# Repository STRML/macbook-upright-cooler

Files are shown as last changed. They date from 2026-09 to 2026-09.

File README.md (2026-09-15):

# MacBook Upright Cooler

Experimental external cooling hardware for a 14-inch MacBook Pro M5 Max used in clamshell mode for sustained local-AI workloads and large code compiles.

The project started from the sealed-adapter approach demonstrated by Samuel Gregory with a llano V12 cooling pad, then branched into a smaller upright dock built around a standard 140 mm fan and a pressure plenum.

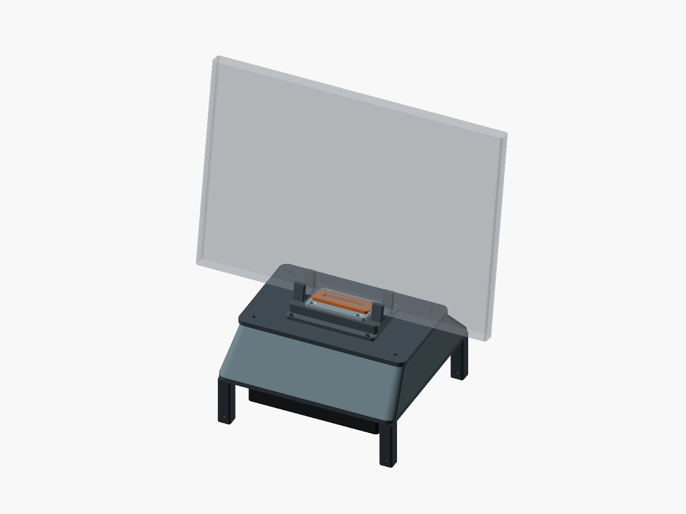
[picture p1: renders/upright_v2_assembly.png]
Upright V2 assembly


[V2 STLs](cad/upright_v2/stl/) · [Assembly guide](cad/upright_v2/README.md) ·
[Validation](docs/VALIDATION.md)

V2 is ready for construction and supervised fit checks. Cooling performance and
the final M5 Max interface have **not** been validated. Start with the blank insert.

For V12-powered validation, use the separate [V12 deck adapter](cad/upright_v2/v12_validation/README.md).
Its cooler footprint is unverified: print the small fit gauge and joint coupons
before committing to the full deck. It reuses V2's upper parts without a second fan.

## Current state

There are three prototypes in this folder:

1. **V12 adapter** - a split adapter for the llano V12, intended to test the sealed-pressure approach on the actual M5 Max.
2. **Upright V1** - a 140 mm fan below a plenum and a narrow gasketed outlet. Preserved as the original concept.
3. **Upright V2** - a tapered shell, removable fan cartridge, 10° cradle, padded stops, and replaceable center insert. The laptop interface remains provisional.

## Repository layout

- `cad/v12_adapter/` — current split V12 adapter STLs
- `cad/upright_v1/` — canonical parametric OpenSCAD source and matching STL
- `cad/upright_v2/` - V2 source, assembly guide, and verified STL snapshot; rebuilds go to `build/upright_v2/`
- `renders/` — current previews
- `docs/HANDOFF.md` — project state, decisions, unknowns, and next steps
- `docs/BENCHMARK_PLAN.md` — proposed A/B validation plan
- `docs/VENT_GEOMETRY.md` — supplied GLB/glTF measurements, online evidence, and remaining fit checks
- `tools/` — mesh validation and reference-model inspection
- `AGENTS.md` — instructions for Codex/other coding agents
- `archive/early_cadquery/` — an earlier CadQuery exploration; **not geometrically identical to the canonical V1 OpenSCAD model**

## Canonical upright V1 geometry

The authoritative source for Upright V1 is:

`cad/upright_v1/upright_macbook_140mm_pressure_dock_v1.scad`

Key dimensions:

- Overall printed envelope: approximately **176 x 176 x 129.5 mm**
- Standard 140 mm fan hole spacing: **124.5 mm**
- Fan opening: **136 mm**
- Laptop guide channel: **19 mm**
- Pressure outlet: **142 x 10 mm**
- Recessed gasket land around the outlet
- Four integrated feet leave space beneath a nominal 25 mm-thick fan

The checked-in STL is reproducible from the OpenSCAD file and is watertight.

## Build

Install OpenSCAD, then:

```bash
make stl
```

The rebuilt STL is written to `build/upright_macbook_140mm_pressure_dock_v1.stl`.

For a quick PNG render:

```bash
make preview
```

For V2's individual parts and assembled/exploded previews:

```bash
make stl-v2
make preview-v2
```

Install the optional Python validation dependencies and run `make check-v2` as
described in the [V2 guide](cad/upright_v2/README.md).

## Design priorities

The project is optimizing for **sustained performance**, not minimum chassis temperature.

- Keep the machine closed and upright if possible.
- Prefer external cooling; do not assume an internal thermal-pad mod is required.
- Feed the Mac's native cooling system with a sealed/pressurized supply rather than merely blowing room air at the bottom shell.
- Keep hot exhaust paths out of the pressurized intake region.
- Make the fan module replaceable so quiet axial fans and higher-static-pressure options can be tested without redesigning the dock.
- Instrument the laptop and compare work completed / clocks / package power over sustained runs.

## References

- [Samuel Gregory's pressure-cooling experiment](https://www.samuelgregory.co.uk/videos/i-sped-up-my-local-ai-64-with-this-100-gadget)
- [llano V12 reference cooler](https://www.amazon.com/dp/B0CYC7T38X)

## Status

This is prototype hardware. The supplied base-M5 visualization helped identify
separate hinge vent banks, but it does not establish a final M5 Max fit. V1's
142 mm outlet would overlap the outer banks in that asset; V2 uses a smaller
experimental center insert. Gasket placement, the closed-lid recess, and required
static pressure still need physical validation. See [vent geometry](docs/VENT_GEOMETRY.md).

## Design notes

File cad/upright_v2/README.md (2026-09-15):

# Upright V2

V2 is a printable construction and fit-check prototype with a removable 140 mm
fan cartridge, a shallow tapered plenum, and a replaceable laptop interface.
The closed laptop leans rearward by 10°. V1 remains unchanged.

**Start with the blank insert and an unpowered fan.** The supplied 3D reference
is a base-M5 visualization, not a verified M5 Max mechanical model. The 44 × 8 mm
open insert is an experimental bench part. Confirm the hinge recess, gasket
contact, and intake/exhaust boundaries before testing it on the Mac. See the
[measurements and sources](../../docs/VENT_GEOMETRY.md).

To supply air from the llano V12 instead of a standalone fan, see the separate
[V12 validation adapter](v12_validation/README.md). Start with its footprint gauge;
the existing V12 outline has not been fit-checked on the cooler.

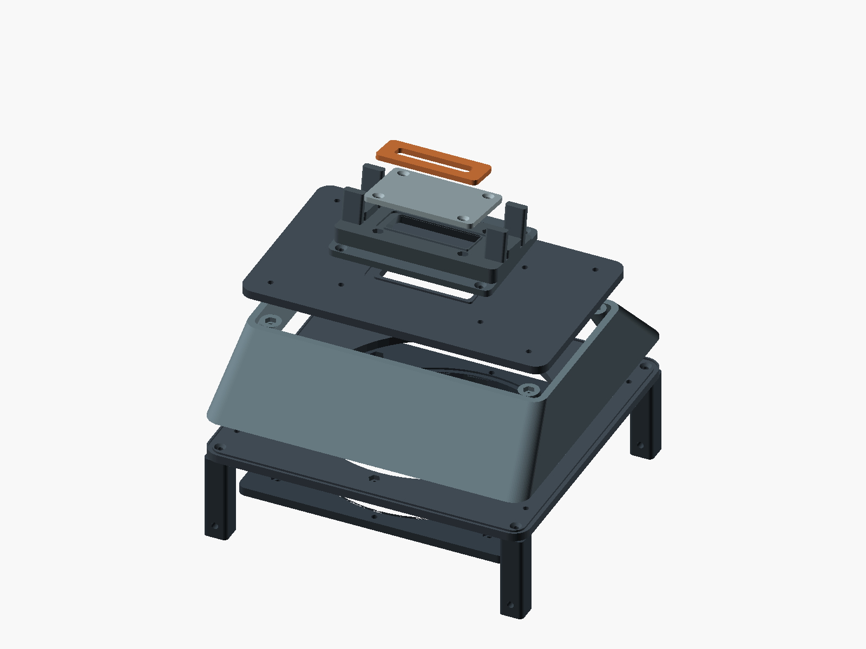
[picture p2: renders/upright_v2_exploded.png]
V2 exploded assembly


## Build and outputs

From the project root, with OpenSCAD installed, run:

```bash
make stl-v2
make preview-v2
python3 -m venv .venv
.venv/bin/pip install -r tools/requirements.txt
make check-v2 PYTHON=.venv/bin/python
```

Set `OPENSCAD` if the executable is not on your path. Outputs stay under
`build/upright_v2/`; `make stl` still builds V1. OpenSCAD's PNG renderer needs
access to a graphics context.

The [checked-in STL snapshot](stl/) contains the verified default prototype.
Rebuild after changing any parameter; the snapshot does not update automatically.
See the [validation record](../../docs/VALIDATION.md) for checks and limitations.

The source selector `PART` exports each part with its print base at Z = 0.
`PART="assembly"` displays the assembly, while `EXPLODE=20` separates it in
preview. `SHOW_REFERENCE` controls the illustrative fan and laptop envelope.
Those reference objects never enter STL exports. The assembly is for viewing;
print the individual parts.

## Parts and measured envelopes

All nine default exports passed the watertightness, consistent winding, positive
volume, and single-solid checks on September 15, 2026. Dimensions are in mm.

| STL | Quantity | Envelope | Print orientation |
|---|---:|---|---|
| `shell.stl` | 1 | 190 × 180 × 40 | Wide opening down |
| `base.stl` | 1 | 190 × 180 × 5 | As exported |
| `cartridge.stl` | 1 | 158 × 158 × 5 | Nut pockets up |
| `lid.stl` | 1 | 180 × 108 × 5 | As exported |
| `cradle.stl` | 1 | 96 × 64 × 29.24 | Flat flange down |
| `insert_blank.stl` | 1 initially | 64 × 42 × 3 | Countersinks up |
| `insert_open.stl` | Alternative | 64 × 42 × 3 | Countersinks up |
| `gasket.stl` | Foam template | 60 × 22 × 4 | Flat |
| `foot.stl` | 4 | 14 × 14 × 52 | Blind nut pocket up |

The assembled printed envelope is **190 × 180 × 129.24 mm**, excluding the laptop,
fasteners, and adhesive foot pads. The shell is 40 mm high, compared with V1's
55 mm plenum. The assembled height is nearly the same as V1 because the separate
cradle and insert need room above it.

Every part fits within a 190 × 180 mm rectangle. Allow room for a brim on the
printer. No split-body seam is needed on the project's nominal 250 mm bed.
Each foot includes a 2 mm square locating tongue that seats inside the base;
its exposed height is 50 mm. The tongue prevents rotation around the fixing bolt.

The shell has open top and bottom faces; its separate lid closes the chamber
after printing. The largest taper advances about 38 mm over 40 mm of height.
Nut-pocket roofs and the 4 mm cable-tie holes have short bridges. Inspect those
layers in your slicer before printing without supports. Mesh validation does not
replace a slicer check or load test.

## Hardware and sealing

Use a nominal 140 × 140 × 25 mm fan, with **124.5 mm** mounting-hole spacing.
It blows upward through a 136 mm opening. The nominal fan underside is 20 mm
above the desk. Fit a 140 mm intake guard before powering the fan, and keep
cables clear of its blades. The guard and fan power/control hardware are separate
parts; include the guard's thickness when choosing the M4 bolt length.

These are starting screw lengths for the modeled stack. Check your actual head,
washer, and fan dimensions before tightening; protruding screws must clear the
fan and neighboring parts.

| Joint | Screws | Nuts | Access |
|---|---|---|---|
| Feet to base | 4 × M3 × 12, countersunk | 4 × M3 | From above, before shell installation |
| Shell to base | 4 × M3 × 16, pan/socket head | 4 × M3 | From inside the open shell |
| Fan to cartridge | 4 × M4 × 30, pan/socket head | 4 × M4 | From below the fan |
| Cartridge to base | 4 × M3 × 12, pan/socket head | 4 × M3 | From below, outside the fan frame |
| Lid to shell | 4 × M3 × 12, pan/socket head | 4 × M3 | From above |
| Cradle to lid | 4 × M3 × 12, countersunk | 4 × M3 | From above the flange |
| Insert to cradle | 4 × M3 × 6, countersunk | 4 × M3 | From above, outside the contact strip |

Total: 24 M3 nuts and four M4 nuts. The nut-pocket allowances are parameters;
test a pocket before printing a full plate. Longer fans use a different `FAN_T`,
which increases the foot height and moves the complete body upward.

Apply closed-cell foam in the recessed seals at the base/shell, shell/lid,
lid/cradle, cradle/insert, and cartridge/base joints. The model seats rigid faces
together and gives the foam a 1.2 mm recess. Select foam that can compress into
that recess, then check for leakage. Seal pressure-chamber fasteners with suitable
bonded washers or a removable sealant; threads and printed nut pockets are not
airtight. Check the fan frame against the cartridge for leakage too.
The base/shell and shell/lid tracks are only 2 mm wide; carefully cut foam cord
or a suitable removable gasket compound may be easier than narrow foam strips.

For laptop contact, start with a **4 mm foam gasket**, using `gasket.stl` as a
cutting template. A TPU alternative needs a compression test before use. The
modeled compressed gasket is 3 mm high. It sits on the 3 mm insert, giving a
6 mm contact height measured perpendicular to the tilted seat. The rigid stops
are 5 mm high and need 1 mm soft pads to reach the same plane. Fit two 12 × 18 mm
stop pads and pad all four laptop-facing guide surfaces. Keep fastener heads
flush and away from the laptop.

## Assemble and test

1. Dry-fit the nuts and screws, then deburr the parts and fit the soft contact pads.
2. Fit the feet and captive base nuts. Seal and fasten the shell to the base.
3. Bolt the fan to its cartridge, then seal and screw the cartridge to the base.
4. Fit the lid's underside nuts before installing the cradle. Seal and fasten the lid.
5. Fit the insert nuts, insert seal, blank insert, and foam gasket.
6. Check the cradle with a padded dummy first. Verify that the stops carry the
   load and that the rigid insert cannot contact the laptop. The 5 mm lid spans
   an approximately 168 × 96 mm cavity and has not been load-tested. Apply the
   laptop-equivalent load at both stops, then a gentle lateral cable load. Stop
   if the lid bows, cracks, or lets the gasket/contact height change.
7. Check the actual Mac's hinge and vent geometry before an unpowered test fit.
8. With the laptop removed and fan guard fitted, bench-test leaks with the blank
   insert. Install the notched open insert only
   after confirming the inlet and exhaust separation, then follow the
   [benchmark plan](../../docs/BENCHMARK_PLAN.md).

The four cartridge screws are separate from the fan bolts and the feet. With the
laptop removed and power disconnected, release those four screws and lower the
fan/cartridge assembly. The shell, lid, and cradle stay together.

Use the holes near the bottoms of the feet for cable ties on either side. Route
the fan cable along a foot and keep the underside inlet clear. The short central
guides leave the laptop's side ports accessible.

## Parameters to verify on the machine

`INTAKE_CENTER_X_TBD`, `INTAKE_W_TBD`, `INTAKE_D_TBD`, and
`EXHAUST_START_ABS_X_TBD` are provisional. The raised cradle ends at X = ±48 mm;
the default exhaust keepout starts at ±52 mm. The stops occupy X = 36..48 mm and
−48..−36 mm. These positions use the gaps in the reference mesh, so they require
checking on the actual Max.

`CHANNEL_W`, `GUIDE_PAD_T`, the gasket dimensions, and its compressed thickness
control contact and fit. Changes outside the documented lean and fan-thickness
options need fresh assembly and clearance checks. The source is editable; its
assertions do not cover every possible combination.

Still to validate physically: printing tolerances, rigidity under cable pull,
gasket compression, vent alignment, exhaust recirculation, fan pressure, and
sustained workload throughput. A watertight STL describes a closed geometric
solid; it does not prove an FDM print or its assembled seams are airtight.

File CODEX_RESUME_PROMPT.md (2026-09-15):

# Codex Resume Prompt

Resume this physical-design project from the repository state.

Read `AGENTS.md`, `README.md`, `docs/HANDOFF.md`, and `docs/BENCHMARK_PLAN.md` first. The current user goal is an elegant upright pressure-cooling dock for a 14-inch M5 Max MacBook Pro in clamshell mode, primarily for sustained AI work and code compiles.

Do not redesign or overwrite `upright_v1`; use it as a baseline. Upright V2 now
exists in `cad/upright_v2/`. Read its `README.md` and `docs/VENT_GEOMETRY.md`
before changing it. It has a replaceable 140 mm fan cartridge, a tapered plenum,
10-degree cradle, replaceable gasket insert, padded stops, and cable-tie paths.

The user supplied `macbook_pro_14-inch_m5.zip` and `macbook-pro-14-inch-m5.zip`
in Downloads. Their GLB/glTF contains useful visualization geometry for a base
M5, but is not a verified M5 Max mechanical model. The central vent-bank frame
is about 51 mm wide, so V2 replaces the V1-sized 142 mm outlet with an explicitly
provisional 44 x 8 mm center opening plus a blank fit-check insert. Preserve the
source qualification and uncertainty documented in `docs/VENT_GEOMETRY.md`.

Next: confirm the actual Max's closed-lid vent recess and padded contact points,
then print/fit-check, leak-test, and benchmark. Generated V2 meshes and previews
are under `build/upright_v2/`; use `make stl-v2`, `make preview-v2`, and
`make check-v2` to reproduce them. The verified snapshot is in
`cad/upright_v2/stl/`; do not let it silently drift from the source. The public
repository is `STRML/macbook-upright-cooler`. Check Git/GitHub state before edits.

The separate `cad/upright_v2/v12_validation/` adapter connects V2's unchanged
upper assembly to a provisional llano V12 deck. The user explicitly has NOT
fit-checked the old V12 panels. Start with `make gauge-v12` and `make coupon-v12`,
then measure the real cooler and establish positive housing restraint before a
powered test. Read that adapter's README for the supported workflow. The source
does not model an unverified V12 body or attachment route. Follow the user's
direct-main publishing instruction; do not open another PR for this work.

The user chose V12 validation first, with standalone intake-clearance, lid-rib,
support, and larger-insert proposals recorded in `docs/BENCHMARK_PLAN.md` for
later. Do not implement those proposals as part of finishing the V12 adapter.
The intended fan direction is pressure into the center hinge intake, with outer
hinge exhausts and side intakes clear. Read the airflow section in
`docs/VENT_GEOMETRY.md` before changing that path.

Important: do not guess final MacBook vent dimensions. Parameterize uncertain geometry and clearly identify measurements that must be taken from the physical machine or a trustworthy mechanical reference before a final STL is produced.

When you generate CAD:

- keep editable source in the repo
- export STL for print testing
- generate a preview image
- report overall dimensions and mesh watertightness
- preserve V1 files unchanged
- explain any assumptions that affect airflow or laptop fit

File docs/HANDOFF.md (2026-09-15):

# Project Handoff

## Resume state: September 15, 2026

Upright V2 now has editable CAD, individual prototype STL exports, and assembly
previews. Start with [the V2 guide](../cad/upright_v2/README.md) and
[the reference-model findings](VENT_GEOMETRY.md). V1 is unchanged.

The supplied Downloads GLB/glTF represents a base M5 and contains useful hinge
detail, but is not a certified M5 Max mechanical reference. Its center-bank
frame is about 51 mm wide; V1's 142 mm outlet would cross into the neighboring
banks in that asset. V2 therefore has a blank insert plus a provisional 44 × 8 mm
center-window insert, with raised hardware confined to a 96 mm-wide cradle.

Next physical step: validate the hinge recess, vent boundaries, and padded stop
locations on the actual Max, using the blank insert first. Then leak-test the
assembled parts and run the benchmark plan. The public repository is
[`STRML/macbook-upright-cooler`](https://github.com/STRML/macbook-upright-cooler).
The user requested direct publication to `main`, without a PR. Check Git and
GitHub before edits. Physical validation is tracked in
[issue #2](https://github.com/STRML/macbook-upright-cooler/issues/2), followed by
[performance testing in #3](https://github.com/STRML/macbook-upright-cooler/issues/3).

## V12 validation adapter

The user asked to adapt V2's bottom for the llano V12 and confirmed that the old
split V12 panels have **not** been fit-checked. The separate
[adapter guide](../cad/upright_v2/v12_validation/README.md) covers a four-piece
footprint gauge, three joint coupons, and a bolted four-tile deck with a continuous
collar. V2's original source and parts remain unchanged; V12 mode removes its fan,
cartridge, and feet.

Next: print the gauge and coupon parts, check the actual cooler's foam/contact
geometry, and identify a safe housing restraint. Do not treat the inherited
381 × 269 mm outline or its 30 mm corner radius as verified V12 dimensions.
Powered use also requires the adapter's load, seal, and stability checks, plus
the existing Mac-side fit checks. No V12 body, foam, or strap route is invented
in the CAD.

The user chose to finish this adapter before revising standalone V2. External
review proposals for 30-35 mm fan clearance, lid ribs, narrower supports, and
measured insert variants are recorded in the benchmark plan. Air is pushed into
the center hinge intake; the outer hinge exhausts and side intakes remain open.
The user's hand check supports that direction, but actual vent boundaries and
flow under external pressure still need checking.

## Goal

Create an elegant, compact external cooling dock for a **14-inch MacBook Pro M5 Max** used primarily in **clamshell mode** for:

- sustained local AI / ML inference and prompt processing
- repeated or large code compiles

The design should recover as much sustained SoC performance as practical without opening the MacBook or adding internal thermal pads unless external airflow proves insufficient.

## Why this exists

The 14-inch Max chassis has substantially less sustained thermal capacity than the 16-inch chassis under heavy combined workloads. The working hypothesis is that a sealed high-static-pressure air supply can improve the Mac's native intake airflow enough to materially delay or reduce throttling.

The Samuel Gregory experiment is the main inspiration: a gaming-laptop pressure cooler plus a custom adapter/seal produced a large sustained local-AI improvement on a 14-inch M5 Max. This repo first reproduces that basic pressure-cooling concept, then aims to package it as a vertical dock.

## Current prototypes

### A. V12 split adapter

Files:

- `cad/v12_adapter/panel_left.stl`
- `cad/v12_adapter/panel_right.stl`

These are a small reconfiguration of the adapter concept used in the Gregory video, sized/split for printing. Each half is approximately 208.5 x 269 x 2 mm and watertight. The assembled panel is roughly 381 x 269 mm. The current interlocking-joint target gap is about 0.2 mm.

Purpose: validate the performance effect on the actual Mac before spending time optimizing aesthetics.

### B. Upright 140 mm pressure dock V1

Files:

- `cad/upright_v1/upright_macbook_140mm_pressure_dock_v1.scad`
- `cad/upright_v1/upright_macbook_140mm_pressure_dock_v1.stl`

Concept:

- standard 140 mm fan mounted underneath
- large low-velocity pressure chamber
- narrow gasketed outlet at the top
- 19 mm channel to guide a closed MacBook vertically
- short rails so the dock does not wrap unnecessarily far around the chassis
- exhaust should remain outside the pressurized volume

Canonical V1 dimensions are parameterized at the top of the OpenSCAD file.

## Important design decisions already made

1. **Do not start with thermal pads.** External pressure cooling gets first priority because it is reversible and there is encouraging evidence it can materially improve sustained AI performance.
2. **Static pressure matters.** A 140 mm form factor is convenient, but the project should not assume a quiet case fan is sufficient. The design should make fan substitution easy.
3. **Avoid a narrow remote hose unless packaging requires it.** Direct fan -> plenum -> gasket is preferred because it minimizes pressure losses.
4. **Preserve intake/exhaust separation.** Hot hinge exhaust must not be encouraged back into the pressure inlet.
5. **Benchmark performance, not just temperature.** A cooler chip at the same sustained package power is less valuable than a hot chip sustaining more useful work.
6. **Keep the current V1 as a baseline.** Make substantial changes as V2 rather than silently mutating V1.

## Unknowns that must be resolved

- Exact location and dimensions of the 14-inch M5 Max intake and exhaust openings in clamshell orientation.
- How much of the rear/hinge intake can practically be sealed to the plenum without restricting exhaust.
- Whether the side intakes need their own pressurized branches or whether feeding the central/rear intake is sufficient.
- Required fan pressure/flow. This should be learned from V12 RPM sweeps before selecting the final standalone fan.
- Best laptop lean angle. A slight rearward lean may provide passive sealing force and improve stability.
- Gasket material/thickness and how much compression is appropriate without scratching or loading the enclosure.
- Whether the V1 19 mm channel is ideal once actual gasket material is selected.

### C. Upright V2 construction and fit-check prototype

- Source: `cad/upright_v2/upright_macbook_140mm_pressure_dock_v2.scad`
- Build: `make stl-v2`, `make preview-v2`, and `make check-v2`
- Individual outputs: `build/upright_v2/`
- Published prototype snapshot: `cad/upright_v2/stl/`
- Printed assembly envelope: 190 × 180 × 129.24 mm at 10° lean
- All nine default STL variants are watertight single solids. The cradle also
  passes at 8° and 12°. These checks do not establish physical print strength,
  airtightness, or final laptop fit.

The shell prints open at both ends and receives a separate lid. Its cartridge
retainers are independent of the fan bolts and feet. Replaceable foam seals join
the pressure parts; the laptop gasket and padded stops share a tilted contact
plane. Cable ties attach through the feet, outside the pressure chamber.

## Original V2 design brief

V1 was inspected before V2 was built. The design brief called for:

- removable 140 mm fan cartridge using standard 124.5 mm mounting pattern
- optional adapters for thicker/high-pressure 140 mm fans
- lower, more sculpted wedge/plenum rather than a rectangular tower
- 8-12 degree rearward laptop lean as a parameter
- replaceable TPU/foam gasket insert rather than relying on hard printed surfaces for the seal
- positive mechanical stop so the Mac cannot drop into the air outlet
- cable routing that works with both left and right USB-C/Thunderbolt connections
- no obstruction of the hinge exhaust zones
- easy disassembly for fan testing
- geometry that can be printed on a typical ~250 mm bed, splitting the body if necessary

The default V2 parts fit inside 190 × 180 mm, so a split-body variant was not
needed. Fan selection and final laptop fit remain experimental.

## Canonical vs archived CAD

The OpenSCAD V1 is canonical. `archive/early_cadquery/` contains an earlier CadQuery/STEP exploration with different base/plenum dimensions. It is retained only as design history and should not be treated as the source for V1.

## Source references

- Gregory experiment: https://www.samuelgregory.co.uk/videos/i-sped-up-my-local-ai-64-with-this-100-gadget
- Reference llano V12: https://www.amazon.com/dp/B0CYC7T38X

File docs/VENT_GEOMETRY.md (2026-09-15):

# Laptop reference geometry

The supplied 3D model supports a narrower center interface for V2. It does **not**
establish a production fit for the M5 Max. Measurements below describe surfaces in
a visualization mesh, including frames and covers, rather than certified vent
apertures. Inspected on September 15, 2026.

## What is confirmed

Apple specifies a **312.6 × 221.2 × 15.5 mm** outer envelope for the 2026 14-inch
M5 Pro/Max. Its service illustrations show two fans, their ducts, and a separate
rear vent/antenna module. Neither the specification nor the inspected service
pages provides dimensions for individual openings.

Sources: [Apple specifications](https://support.apple.com/en-gb/126318),
[Apple exploded view](https://support.apple.com/en-us/125815), and
[Apple vent module procedure](https://support.apple.com/en-us/125803).

SVALT, a cooling-hardware manufacturer, describes the 14-inch Pro/Max family as
having side intakes and a central hinge intake, with hot exhaust at both hinge
ends. Its separate base-M5 description identifies a single fan. This supports
the airflow concept but does not prove that the two models have identical vent
dimensions. [SVALT model guide](https://svalt.com/blogs/svalt/laptops).

## Airflow direction

The intended stock flow for the two-fan Pro/Max is:

| Opening | Stock direction | Dock treatment |
|---|---|---|
| Center hinge vent | Cool air enters | Feed from the sealed center insert |
| Left and right outer hinge vents | Hot air leaves | Keep outside the seal and clear of supports |
| Side chassis slots | Cool air enters | Leave open; do not tape them shut |

This follows SVALT's description for the 2021-2026+ 14-inch M1-M5 Pro/Max
family, not its separate single-fan base-M5 entry. Apple service drawings support
the two-fan layout but do not establish flow direction at every opening. On
September 15, 2026, the user reported hot outward flow at the outer hinge vents,
apparent intake at the center, and cool side slots. That is consistent with the
description, but is not a measured flow map.

V2 pushes air into the center intake. With a standalone fan, its intake faces the
desk and its discharge faces the plenum; check the fan's airflow arrow or actual
flow before installation. With the V12 adapter, the V12 supplies the pressure and
the standalone fan is removed. Pulling through the same center connection would
oppose its normal intake role. Exhaust extraction would need a different adapter
at the two outer vents and is not part of this design.

Before fitting the dock, check direction during a sustained load with a narrow
paper strip held securely a few millimeters outside each opening. Never insert
it, release it, or cover the vent. Record movement toward or away from the case;
temperature alone cannot establish direction. Repeat with the pressure source
at low speed after all mechanical checks pass. Added pressure may send some air
out through the side intakes instead of through the heatsinks. Keep them open
and record that behavior during the speed sweep rather than assuming all added
flow follows the intended path.

## Supplied files and provenance

The two Downloads archives contain an open-lid model:

- `macbook_pro_14-inch_m5.zip`: `scene.gltf`, `scene.bin`, textures, and a license.
- `macbook-pro-14-inch-m5.zip`: `source/macbook_pro_14_inch_M5.glb` and textures.

The glTF metadata credits “Apple User” and links to
[MacBook Pro 14-inch M5 on Sketchfab](https://sketchfab.com/3d-models/macbook-pro-14-inch-m5-652a992f4f244122ae251f9cbb81da1e).
The archive entries date to October 15, 2025. This predates the 2026 M5 Pro/Max.
The metadata does not establish that this is an Apple engineering model.

Both formats contain 44 geometries and 163,918 triangles, with matching scene
bounds. At the glTF meter-to-millimeter scale, width is **311.730 mm**. Scaling
that width to Apple's envelope requires a factor of **1.00279135**. The values
below retain the original scale; scaling the whole mesh would not resolve its
model identity or modeling tolerances.

The originals remain in Downloads. They are not redistributed with the dock.
Archive SHA-256 values identify the inspected inputs:

```text
macbook_pro_14-inch_m5.zip
8e0a6a0f3d5dbc4d95af7a3dc4d497db02db5f969b665d1a111a3dfa906ae67f
macbook-pro-14-inch-m5.zip
23eaa3a1fac218d26dcd32061c8e82add21565c6362a2ae14dc4012e4c40db4a
```

## Geometry recovered from the mesh

Coordinates use X across the laptop, Y upward through its thickness, and Z from
the hinge toward the front. X = 0 is approximately the centerline. Apply each
scene-node transform before measuring vertices.

The connected surfaces of glTF node `Object_44` provide these bounds, in mm:

| Surface | X minimum | X maximum | Width |
|---|---:|---:|---:|
| Rear center-bank frame | −25.285 | 25.286 | 50.571 |
| Rear left-bank frame | −118.884 | −54.466 | 64.418 |
| Rear right-bank frame | 54.467 | 118.884 | 64.417 |
| Inner center-bank surface | −26.559 | 26.560 | 53.119 |

The rear frames extend from Y = −6.737 to 2.353 mm and Z = −104.820 to
−102.342 mm. Their height includes structure hidden by the hinge. **Do not use
9.09 mm as the clear clamshell opening height.** The hinge recess and closed-lid
occlusion still need measurement on the machine.

Node `Object_40` also has long side surfaces spanning Z = −20.200 to 86.475 mm.
These are visual backing surfaces, so their bounds do not establish side-intake
aperture dimensions.

To reproduce the measurements and orthographic reference image after extracting
the glTF archive, run:

```bash
python3 -m venv .venv
.venv/bin/pip install -r tools/requirements.txt
.venv/bin/python tools/inspect_reference.py /path/to/extracted/scene.gltf
```

The image is written to `build/upright_v2/reference.png`.

## V2 decisions and remaining fit checks

V1's 142 mm-wide outlet reaches X = ±71 mm. It would overlap both outer banks in
this asset. V1 remains preserved as a historical baseline; V2 uses an explicitly
experimental 44 × 8 mm center window and a blank insert for initial fit and leak
checks. This is a design choice inside the estimated center bank, not a measured
Mac aperture. A small port may also limit airflow; benchmark it before selecting
the final size or fan.

V2 keeps its raised central cradle inside a provisional X = ±52 mm exhaust
keepout and locates padded supports in the gaps beside the center bank. The seal
and supports are replaceable so that physical measurements can correct them.

Before cooling the laptop through the insert:

1. Confirm the center intake and both exhaust boundaries on the actual M5 Max.
2. Measure the closed-lid opening height and recess from the lowest hinge edge.
3. Check that padded stops land on solid chassis and keep rigid parts clear.
4. Verify gasket contact and airflow direction, then follow the
   [benchmark plan](BENCHMARK_PLAN.md).

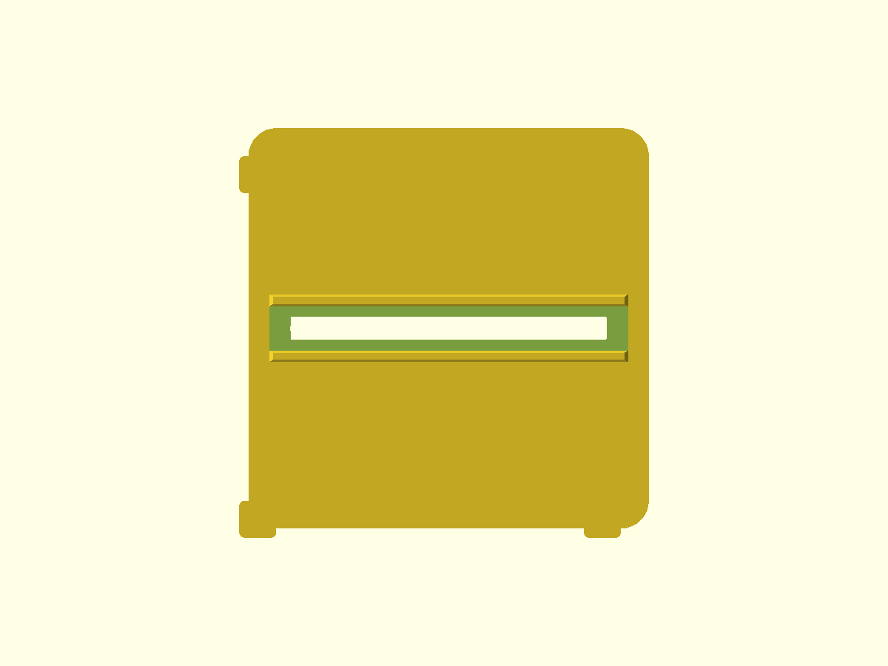
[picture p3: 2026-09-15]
renders/upright_macbook_140mm_pressure_dock_v1_preview.png

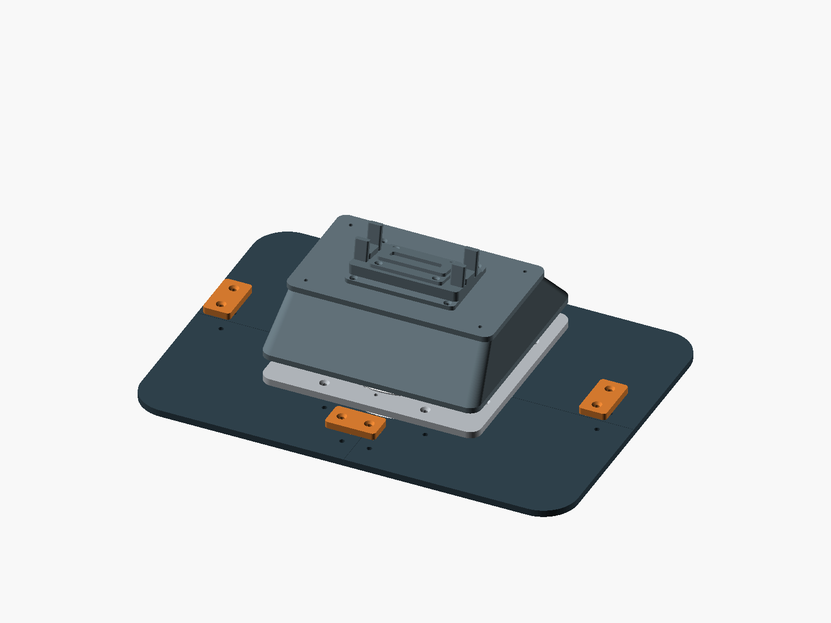
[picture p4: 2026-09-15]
renders/upright_v12_exploded.png

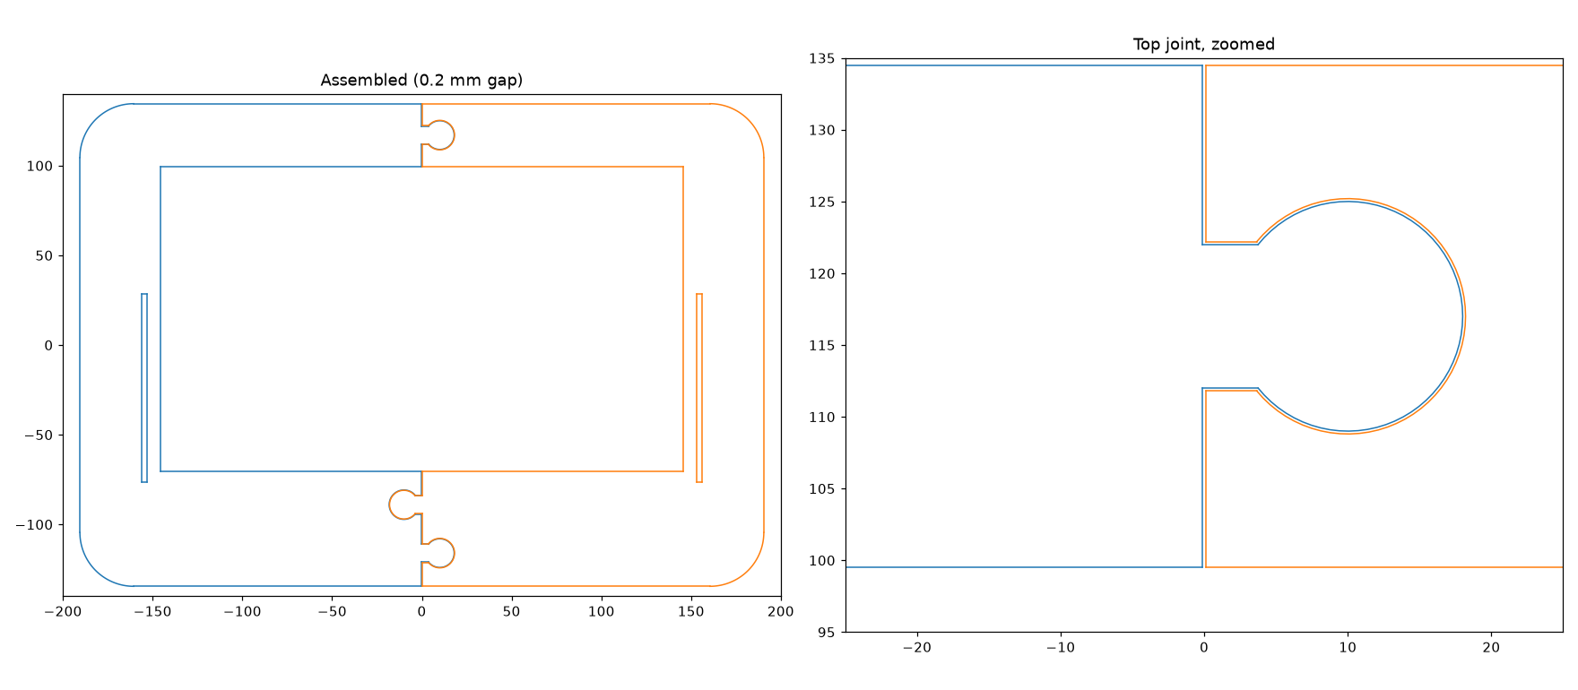
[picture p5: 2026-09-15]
renders/v12_adapter_split_preview.png

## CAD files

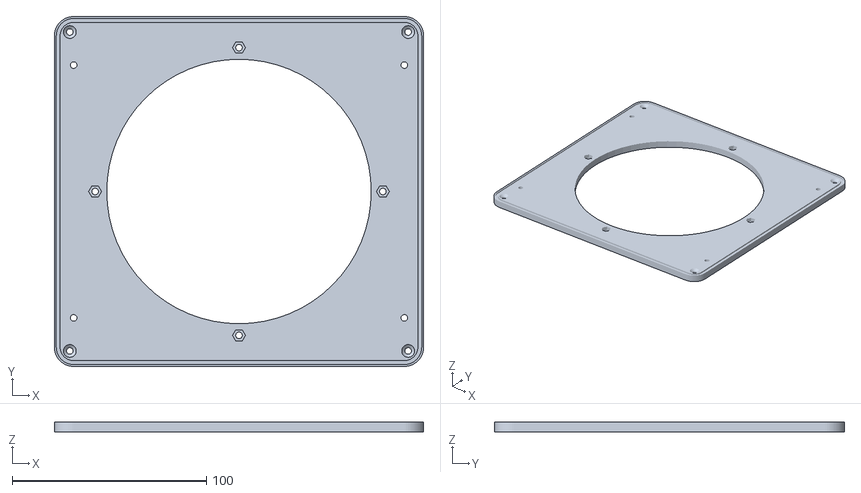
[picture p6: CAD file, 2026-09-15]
cad/upright_v2/stl/base.stl
190.0 x 180.0 x 5.00

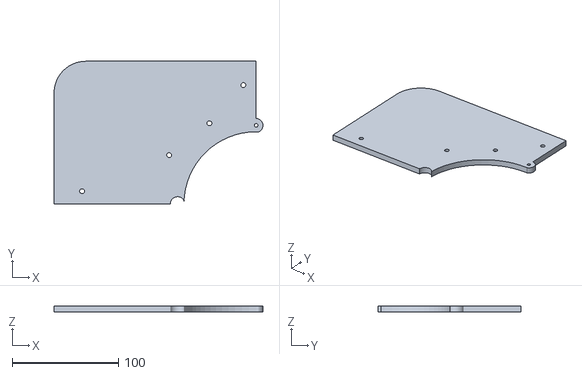
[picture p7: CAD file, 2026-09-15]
cad/upright_v2/v12_validation/stl/deck_nw.stl
197.0 x 134.3 x 6.00

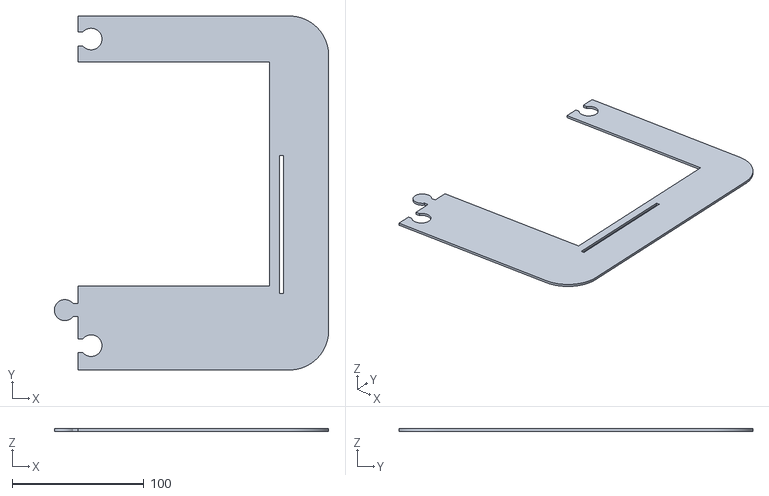
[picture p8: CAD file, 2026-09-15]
cad/v12_adapter/panel_right.stl
208.5 x 269.0 x 2.00

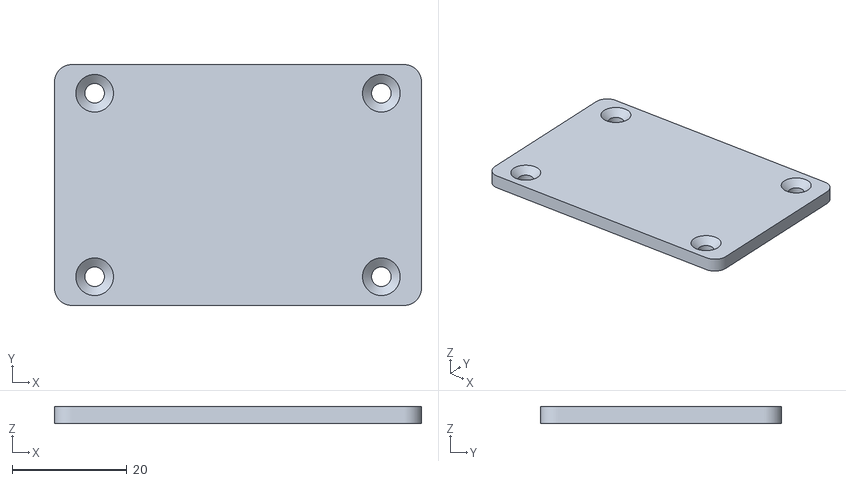
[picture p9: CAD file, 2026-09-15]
cad/upright_v2/stl/insert_blank.stl
64.0 x 42.0 x 3.00

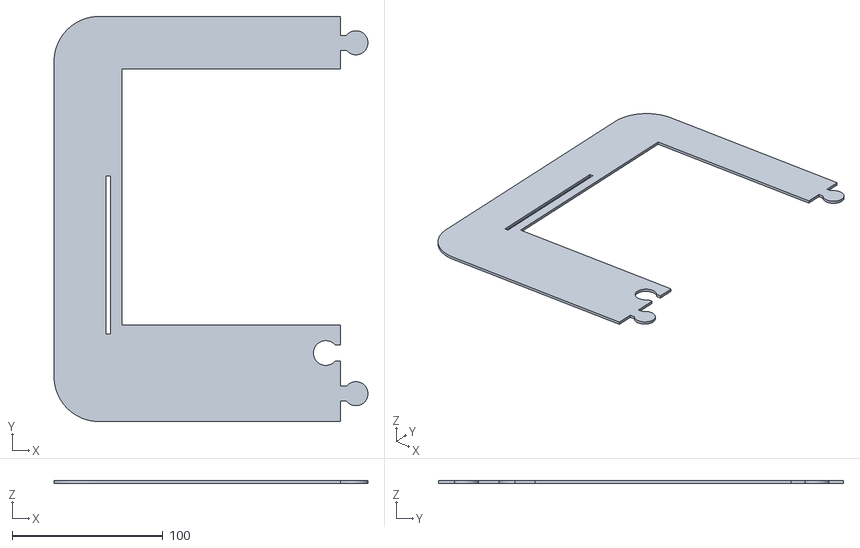
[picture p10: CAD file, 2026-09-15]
cad/v12_adapter/panel_left.stl
208.5 x 269.0 x 2.00

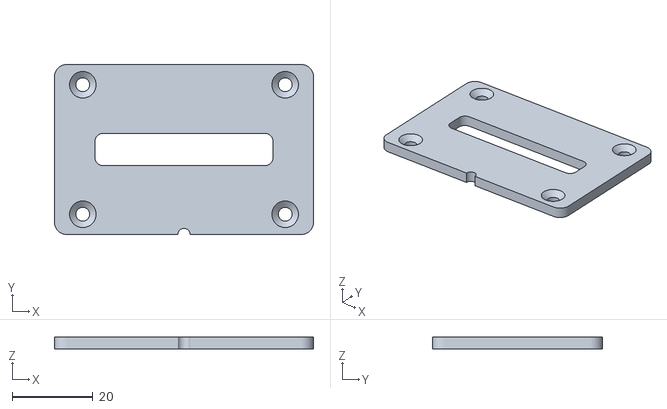
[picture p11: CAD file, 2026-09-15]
cad/upright_v2/stl/insert_open.stl
64.0 x 42.0 x 3.00

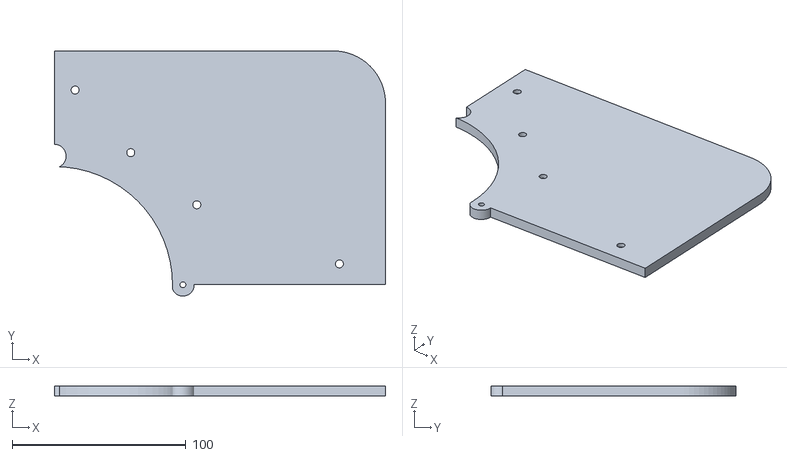
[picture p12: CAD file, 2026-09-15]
cad/upright_v2/v12_validation/stl/deck_ne.stl
190.3 x 141.0 x 6.00

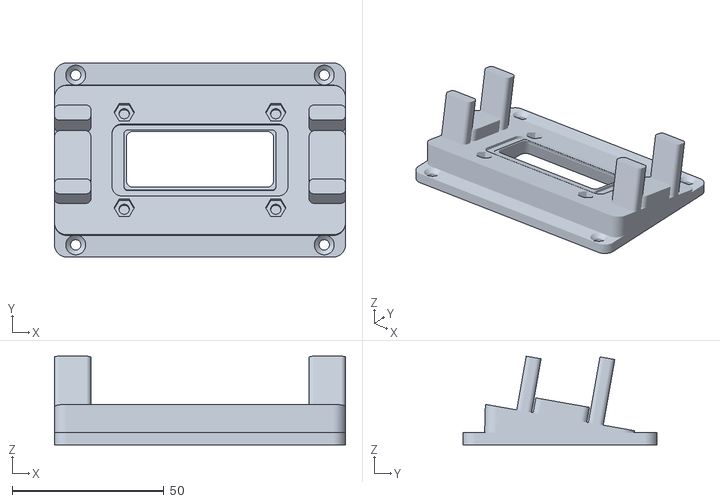
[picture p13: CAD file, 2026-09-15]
cad/upright_v2/stl/cradle.stl
96.0 x 64.0 x 29.2

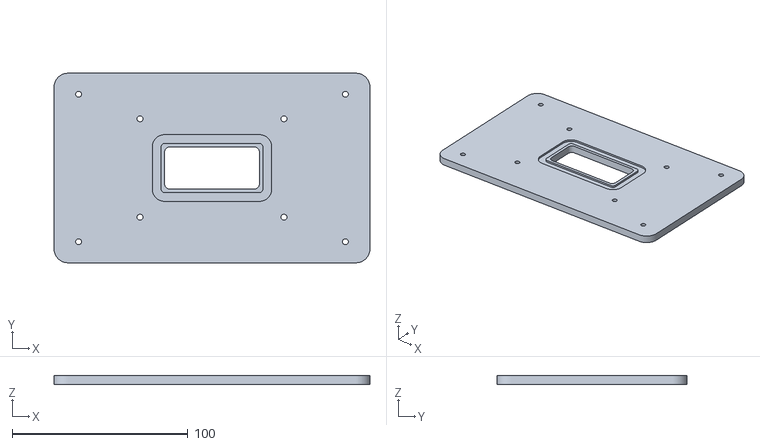
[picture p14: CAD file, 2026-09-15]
cad/upright_v2/stl/lid.stl
180.0 x 108.0 x 5.00

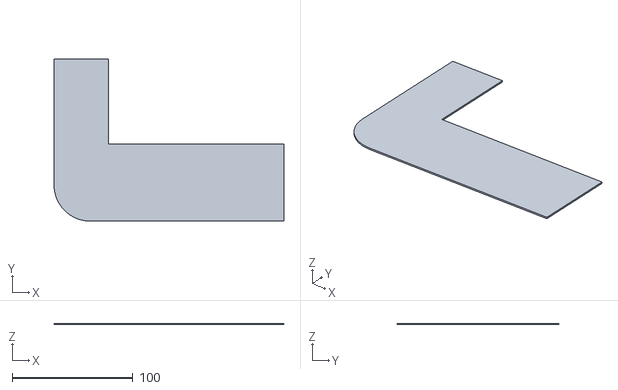
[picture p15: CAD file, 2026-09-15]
cad/upright_v2/v12_validation/stl/gauge_sw.stl
190.4 x 134.4 x 1.20

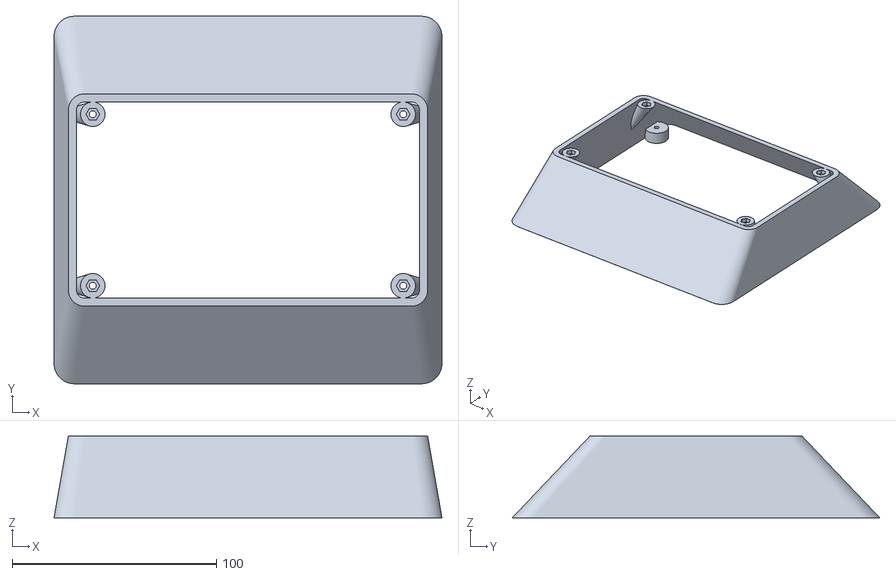
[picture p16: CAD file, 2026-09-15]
cad/upright_v2/stl/shell.stl
190.0 x 180.0 x 40.0

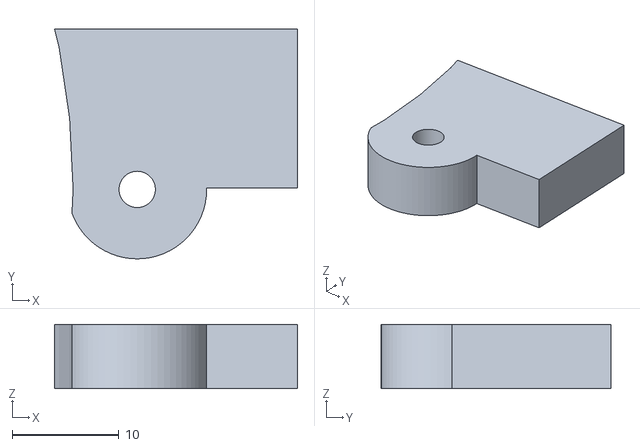
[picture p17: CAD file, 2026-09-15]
cad/upright_v2/v12_validation/stl/coupon_ne.stl
22.7 x 21.5 x 6.00

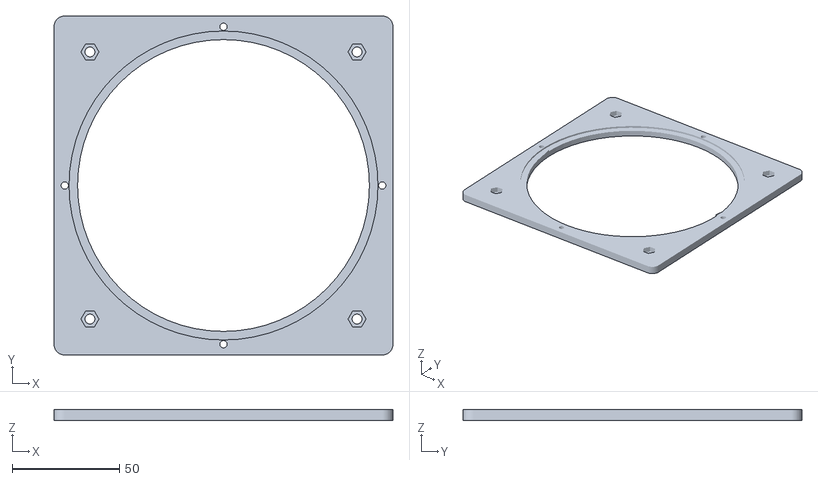
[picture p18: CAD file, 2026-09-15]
cad/upright_v2/stl/cartridge.stl
158.0 x 158.0 x 5.00

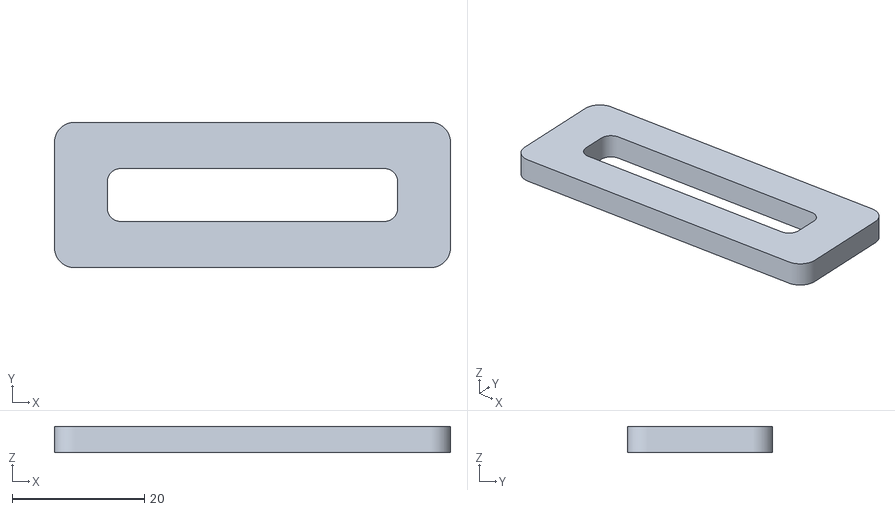
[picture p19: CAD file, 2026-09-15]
cad/upright_v2/stl/gasket.stl
60.0 x 22.0 x 4.00

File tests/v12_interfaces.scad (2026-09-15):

// Independent checks of the default V2/V12 mating contract. Units: mm.
use <../cad/upright_v2/v12_validation/upright_v2_v12_validation.scad>
use <../cad/upright_v2/upright_macbook_140mm_pressure_dock_v2.scad>
$fn = 64;
TEST = "air_path";
CONTACT_PROBE_MM = 0.001;
QUADS = [[1,1],[-1,1],[-1,-1],[1,-1]];
M3_POINTS = [[74,0],[0,74],[-74,0],[0,-74]];
M4_COLLAR = concat([for(x=[-82,82]) for(y=[-46,46]) [x,y]],
                   [for(x=[-44,44]) for(y=[-76,76]) [x,y]]);
M4_BRIDGES = concat([for(x=[-12,12]) for(y=[-112,112]) [x,y]],
                    [for(x=[-164,164]) for(y=[-12,12]) [x,y]]);
// Independent fit envelope for a typical purchased nut plus a modest
// dimensional allowance. Keep this independent from the source pocket
// allowance so the zero-clearance regression cases remain meaningful.
NUT_TEST_AF_ALLOWANCE = 0.20;
NUT_TEST_Z_ALLOWANCE = 0.15;

module stack_lower() {
    v12_deck();
    translate([0,0,6]) v12_collar();
    translate([0,0,12]) base();
}
module collar_probe(overlap_mm=0) {
    // Lift the modeled-baseline Z=6 contact plane by the allowance. A positive overlap
    // argument deliberately moves the real collar into the real deck.
    translate([0,0,6 + CONTACT_PROBE_MM - overlap_mm]) v12_collar();
}
module base_probe() {
    translate([0,0,12 + CONTACT_PROBE_MM]) base();
}
module m3_hardware() {
    // 2.5 mm pan head, 0.5 mm washer, 16 mm under-head length.
    for(p=M3_POINTS) translate([p[0],p[1],0]) {
        translate([0,0,0.5]) cylinder(d=5.6,h=2.5);
        translate([0,0,3]) cylinder(d=7,h=0.5);
        translate([0,0,3]) cylinder(d=3,h=16);
    }
}
module m4_hardware() {
    // Screw-only check retained separately from the nut-pocket fit check below.
    // Conservative 8 mm head and 4 mm shank, flush at Z=12.
    for(p=concat(M4_COLLAR,M4_BRIDGES)) translate([p[0],p[1],0]) {
        cylinder(d=4,h=10);
        translate([0,0,10]) cylinder(d1=4,d2=8,h=2);
    }
}
module m4_hardware_probe() {
    // Keep the hardware dimensions unchanged; trim only its probe's top face
    // below the modeled-baseline Z=12 bridge plane to avoid coplanar CGAL contact.
    intersection() {
        m4_hardware();
        translate([0,0,(12 - CONTACT_PROBE_MM) / 2])
            cube([400,400,12 - CONTACT_PROBE_MM],center=true);
    }
}
module m4_nut_fit_envelopes(af_allowance=NUT_TEST_AF_ALLOWANCE,
                            z_allowance=NUT_TEST_Z_ALLOWANCE) {
    // Start and finish just inside the modeled-baseline faces to avoid coplanar
    // contact. The resulting envelope still tests both pocket walls and roof.
    for(p=concat(M4_COLLAR,M4_BRIDGES)) translate([p[0],p[1],CONTACT_PROBE_MM])
        v12_hex_nut(v12_m4_nut_af() + af_allowance,
                    v12_m4_nut_h() + z_allowance - 2 * CONTACT_PROBE_MM);
}

if(TEST=="positive_control") cube([2,2,2]);
else if(TEST=="empty_control") intersection() {
    cube([1,1,1]); translate([2,0,0]) cube([1,1,1]);
}
else if(TEST=="positive_collision") intersection() {
    v12_deck(); collar_probe(0.1);
}
else if(TEST=="tile_overlap")
    for(i=[0:2]) for(j=[i+1:3]) intersection() {
        v12_deck_tile(QUADS[i][0],QUADS[i][1]);
        v12_deck_tile(QUADS[j][0],QUADS[j][1]);
    }
else if(TEST=="deck_collar") intersection() {
    v12_deck(); collar_probe();
}
else if(TEST=="base_collar") intersection() {
    base_probe(); translate([0,0,6]) v12_collar();
}
else if(TEST=="bridges_clear") intersection() {
    v12_bridges();
    union() { translate([0,0,6]) v12_collar(); v12_upper(); }
}
else if(TEST=="m3_hardware") intersection() { stack_lower(); m3_hardware(); }
else if(TEST=="m4_hardware") intersection() {
    union() { stack_lower(); v12_bridges(); }
    m4_hardware_probe();
}
else if(TEST=="m4_nut_fit" ||
        TEST=="m4_nut_fit_no_clearance" ||
        TEST=="m4_nut_fit_no_depth_clearance") intersection() {
    // The deck must clear the real hex solids at all 16 nut pockets.
    v12_deck();
    m4_nut_fit_envelopes();
}
else if(TEST=="positive_nut_collision") intersection() {
    // Deliberately over-size the nut envelope. This must produce a collision
    // if the fit test is actually looking at pocket walls and roof.
    v12_deck();
    m4_nut_fit_envelopes(v12_m4_nut_clearance() + 0.95,
                         v12_m4_nut_z_clearance() + 0.80);
}
else if(TEST=="air_path") intersection() {
    stack_lower();
    // Nearly the full 136 mm inlet, through adapter and unchanged V2 base.
    translate([0,0,-1]) cylinder(d=135.8,h=19);
}
else if(TEST=="gauge_window") intersection() {
    union() for(q=QUADS) v12_gauge_tile(q[0],q[1]);
    // A membrane over the window can still be a watertight STL.
    translate([0,14.5,0.6]) cube([290,169,1.3],center=true);
}
else if(TEST=="deck_material") difference() {
    // Check actual tile thickness away from tabs; a tall tab alone can hide
    // an accidentally half-height tile in an overall bounding-box check.
    for(x=[-110,110]) for(y=[-60,60])
        translate([x,y,3]) cube([2,2,5.8],center=true);
    v12_deck();
}
else assert(false,"Unknown interface test");

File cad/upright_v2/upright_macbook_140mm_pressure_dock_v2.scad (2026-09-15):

// Upright V2 modular fit-check prototype. Units: mm.
// X across hinge, +Y rearward lean, Z above desk.
// See README.md here and ../../docs/VENT_GEOMETRY.md.
// The base-M5 visualization is not certified M5 Max vent geometry.
$fn = 64;
PART = "assembly";
EXPLODE = 0;
SHOW_REFERENCE = true;
INTERFACE_OPEN = false; // blank for initial fit / leakage checks

BASE_W = 190;
BASE_D = 180;
BASE_T = 5;
WALL = 4;
SHELL_H = 40;
TOP_W = 176;
TOP_D = 104;
LID_W = 180;
LID_D = 108;
LID_T = 5;

FAN_SIZE = 140;
FAN_T = 25;
FAN_HOLE_SPACING = 124.5;
FAN_HOLE_D = 4.6;
FAN_OPEN_D = 136;
CARTRIDGE_W = 158;
CARTRIDGE_T = 5;
DESK_INTAKE_CLEARANCE = 20;
FOOT_W = 14;
FOOT_X = 87;
FOOT_Y = 82;

LEAN_DEG = 10; // supported range 8..12
CHANNEL_W = 19; // prototype clearance; pad both guide faces
GUIDE_PAD_T = 1;
GUIDE_W = 12;
GUIDE_T = 5;
GUIDE_X = 42;
GUIDE_FRONT_H = 18;
GUIDE_REAR_H = 22;
CRADLE_W = 96;
CRADLE_D = 64;
CRADLE_BASE_T = 4;
SEAT_Z = 9;
PORT_W = 54;
PORT_D = 24;
SEAT_PORT_W = 48;
SEAT_PORT_D = 18;

// Measurement-dependent interface. Defaults below are prototype choices.
INTAKE_CENTER_X_TBD = 0;
INTAKE_W_TBD = 44;
INTAKE_D_TBD = 8;
EXHAUST_START_ABS_X_TBD = 52; // raised cradle stays inside this boundary
INSERT_W = 64;
INSERT_D = 42;
INSERT_T = 3;
GASKET_W = 60;
GASKET_D = 22;
GASKET_FREE_H = 4;
GASKET_COMPRESSED_H = 3;
STOP_PAD_T = 1;
CONTACT_Z = INSERT_T + GASKET_COMPRESSED_H;
STOP_H = CONTACT_Z - STOP_PAD_T;

M3_D = 3.4;
M3_NUT_AF = 5.8; // 5.5 mm nominal plus print allowance
M3_NUT_H = 2.8;
M4_NUT_AF = 7.3;
M4_NUT_H = 3.4;
SEAL_RECESS = 1.2; // foam must compress into recess so rigid faces seat
EPS = 0.02;

FOOT_H = DESK_INTAKE_CLEARANCE + FAN_T + CARTRIDGE_T;
BASE_Z = FOOT_H;
SHELL_Z = BASE_Z + BASE_T;
LID_Z = SHELL_Z + SHELL_H;
CRADLE_Z = LID_Z + LID_T;
CARTRIDGE_Z = BASE_Z - CARTRIDGE_T;
SHELL_FIX = [[-85,-65],[-85,65],[85,-65],[85,65]];
LID_FIX = [[-76,-42],[-76,42],[76,-42],[76,42]];
CART_FIX = [[-74,0],[74,0],[0,-74],[0,74]];
CRADLE_FIX = [[-41,-28],[-41,28],[41,-28],[41,28]];
INSERT_FIX = [[-25,-16],[-25,16],[25,-16],[25,16]];
PARTS = ["assembly","shell","base","cartridge","lid","cradle",
         "insert_blank","insert_open","gasket","foot"];

assert(len([for (p=PARTS) if (p==PART) p]) == 1, "Unknown PART");
assert(LEAN_DEG>=8 && LEAN_DEG<=12, "LEAN_DEG must be 8..12");
assert(WALL>=3 && WALL<=5, "WALL must be 3..5 for the fixing bosses");
assert(FAN_T>0 && DESK_INTAKE_CLEARANCE>=15, "Invalid fan / desk clearance");
assert(FOOT_X-FOOT_W/2>CARTRIDGE_W/2, "Cartridge must clear feet");
assert(FAN_SIZE/2<74-M3_D/2, "Fan frame obstructs cartridge screws");
assert(FAN_HOLE_SPACING+FAN_HOLE_D<CARTRIDGE_W, "Fan holes exceed carrier");
assert(CHANNEL_W-2*GUIDE_PAD_T>15.5, "Channel needs padded insertion clearance");
assert(CRADLE_W/2<EXHAUST_START_ABS_X_TBD, "Cradle enters exhaust keepout");
assert(INTAKE_W_TBD>=4 && abs(INTAKE_CENTER_X_TBD)+INTAKE_W_TBD/2+3<=GASKET_W/2,
       "Keep at least 3 mm of gasket beside the inlet");
assert(INTAKE_D_TBD>=4 && INTAKE_D_TBD+6<=GASKET_D, "Invalid inlet depth");
assert(abs(INTAKE_CENTER_X_TBD)+INTAKE_W_TBD/2<=SEAT_PORT_W/2 &&
       INTAKE_D_TBD<=SEAT_PORT_D, "Inlet exceeds the cradle air path");
assert(GASKET_FREE_H>GASKET_COMPRESSED_H && GASKET_COMPRESSED_H>0 && STOP_H>0,
       "Invalid stop/seal stack");

module rr(w,d,r=3) { offset(r=r) square([w-2*r,d-2*r],center=true); }
module slab(w,d,h,r=3) { linear_extrude(height=h) rr(w,d,r); }
module at_points(points) { for (p=points) translate([p[0],p[1],0]) children(); }
module bore(h,d=M3_D) { translate([0,0,-EPS]) cylinder(d=d,h=h+2*EPS); }
module nut(af=M3_NUT_AF,h=M3_NUT_H) { cylinder(d=af/cos(30),h=h,$fn=6); }
module countersink(top) {
    translate([0,0,top-1.6]) cylinder(d1=M3_D,d2=6.6,h=1.6+EPS);
}
module rectangular_seal(ow,od,iw,id,h=SEAL_RECESS,r=7,ir=5) {
    difference() {
        slab(ow,od,h,r);
        translate([0,0,-EPS]) slab(iw,id,h+2*EPS,ir);
    }
}
module seat() { translate([0,0,SEAT_Z]) rotate([-LEAN_DEG,0,0]) children(); }

module base() {
    difference() {
        slab(BASE_W,BASE_D,BASE_T,10);
        bore(BASE_T,FAN_OPEN_D);
        at_points(SHELL_FIX) { bore(BASE_T); nut(h=M3_NUT_H+EPS); }
        at_points(CART_FIX) {
            bore(BASE_T);
            translate([0,0,BASE_T-M3_NUT_H]) nut(h=M3_NUT_H+EPS);
        }
        // Separate countersunk foot screws; install before the shell.
        for (x=[-FOOT_X,FOOT_X]) for (y=[-FOOT_Y,FOOT_Y])
            translate([x,y,0]) {
                bore(BASE_T); countersink(BASE_T);
                translate([0,0,-EPS]) slab(10.5,10.5,2.2+EPS,2.25);
            }
        translate([0,0,BASE_T-SEAL_RECESS])
            rectangular_seal(188,178,184,174,SEAL_RECESS+EPS,9,7);
    }
}

module tapered(w0,d0,w1,d1,h,r0=10,r1=8,extra=0) {
    hull() {
        translate([0,0,-extra]) slab(w0,d0,EPS,r0);
        translate([0,0,h-EPS+extra]) slab(w1,d1,EPS,r1);
    }
}
module shell() {
    difference() {
        union() {
            difference() {
                tapered(BASE_W,BASE_D,TOP_W,TOP_D,SHELL_H);
                tapered(BASE_W-2*WALL,BASE_D-2*WALL,
                        TOP_W-2*WALL,TOP_D-2*WALL,SHELL_H,
                        10-WALL,8-WALL,EPS);
            }
            // Short lower bosses grow from the build plate into the wall.
            at_points(SHELL_FIX) cylinder(r=8,h=8);
            // Sloping upper bosses grow from the side wall, without floating pads.
            for (p=LID_FIX) hull() {
                translate([sign(p[0])*90,p[1],SHELL_H-24]) cylinder(r=2,h=EPS);
                translate([p[0],p[1],SHELL_H-EPS]) cylinder(r=6,h=EPS);
            }
        }
        at_points(SHELL_FIX) bore(8);
        at_points(LID_FIX) {
            translate([0,0,SHELL_H-12]) bore(12);
            translate([0,0,SHELL_H-M3_NUT_H]) nut(h=M3_NUT_H+EPS);
        }
    }
}

module cartridge() {
    difference() {
        slab(CARTRIDGE_W,CARTRIDGE_W,CARTRIDGE_T,5);
        bore(CARTRIDGE_T,FAN_OPEN_D);
        at_points(CART_FIX) bore(CARTRIDGE_T);
        for (x=[-FAN_HOLE_SPACING/2,FAN_HOLE_SPACING/2])
            for (y=[-FAN_HOLE_SPACING/2,FAN_HOLE_SPACING/2])
                translate([x,y,0]) {
                    bore(CARTRIDGE_T,FAN_HOLE_D);
                    translate([0,0,CARTRIDGE_T-M4_NUT_H])
                        nut(M4_NUT_AF,M4_NUT_H+EPS);
                }
        translate([0,0,CARTRIDGE_T-SEAL_RECESS]) difference() {
            cylinder(d=144,h=SEAL_RECESS+EPS);
            translate([0,0,-EPS]) cylinder(d=136,h=SEAL_RECESS+3*EPS);
        }
    }
}

module lid() {
    difference() {
        slab(LID_W,LID_D,LID_T,8);
        translate([0,0,-EPS]) slab(PORT_W,PORT_D,LID_T+2*EPS,3);
        at_points(LID_FIX) bore(LID_T);
        at_points(CRADLE_FIX) { bore(LID_T); nut(h=M3_NUT_H+EPS); }
        translate([0,0,-EPS])
            rectangular_seal(174,102,170,98,SEAL_RECESS+EPS,7,5);
        translate([0,0,LID_T-SEAL_RECESS])
            rectangular_seal(68,38,58,28,SEAL_RECESS+EPS,7,2);
    }
}

module cradle() {
    difference() {
        union() {
            slab(CRADLE_W,CRADLE_D,CRADLE_BASE_T,4);
            hull() {
                slab(CRADLE_W,50,EPS,4);
                seat() translate([0,0,-EPS]) slab(CRADLE_W,50,EPS,4);
            }
            seat() for (x=[-GUIDE_X,GUIDE_X]) {
                translate([x,0,-EPS]) slab(GUIDE_W,18,STOP_H+EPS,2);
                for (s=[-1,1])
                    translate([x,s*(CHANNEL_W+GUIDE_T)/2,-EPS])
                        slab(GUIDE_W,GUIDE_T,
                             (s>0 ? GUIDE_REAR_H : GUIDE_FRONT_H)+EPS,1.5);
            }
        }
        // Continuous path from flat lid port to the tilted insert.
        hull() {
            translate([0,0,-1]) slab(PORT_W,PORT_D,EPS,3);
            seat() slab(SEAT_PORT_W,SEAT_PORT_D,1,2);
        }
        at_points(CRADLE_FIX) { bore(CRADLE_BASE_T); countersink(CRADLE_BASE_T); }
        seat() at_points(INSERT_FIX) {
            translate([0,0,-5]) bore(5);
            translate([0,0,-M3_NUT_H]) nut(h=M3_NUT_H+EPS);
        }
        seat() translate([0,0,-SEAL_RECESS])
            rectangular_seal(58,24,50,20,SEAL_RECESS+EPS,3,1);
    }
}
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

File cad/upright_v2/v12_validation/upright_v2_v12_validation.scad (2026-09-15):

// Upright V2 / llano V12 provisional validation geometry. Units: mm.
//
// This file is a gauge and hardware-layout study, not a certified or powered
// fit. The V12 cooler panels have not been fit-checked on the user's llano V12
// cooler, and the
// laptop's actual intake/exhaust geometry remains a measurement prerequisite.
// V12_W_TBD, V12_D_TBD, and V12_R_TBD intentionally retain the TBD suffix.
use <../upright_macbook_140mm_pressure_dock_v2.scad>

$fn = 64;

PART = "assembly";
EXPLODE = 0;
SHOW_REFERENCE = true;

// Legacy V12 outer panel profile. Confirmed from the existing STL envelope;
// re-measure the physical cooler before treating these as production values.
V12_W_TBD = 381;
V12_D_TBD = 269;
V12_R_TBD = 30;

// Unpowered coverage gauge. The rectangle is deliberately not a vent proxy.
V12_GAUGE_T = 1.2;
V12_GAUGE_OPEN_W_TBD = 291;
V12_GAUGE_OPEN_D_TBD = 170;
V12_GAUGE_OPEN_Y_TBD = 14.5;
V12_GAUGE_SEAM_GAP = 0.3; // total gap across each split seam

// Structural mating contract.
V12_DECK_T = 6;
V12_COLLAR_W = 190;
V12_COLLAR_D = 180;
V12_COLLAR_T = 6;
V12_COLLAR_R = 10;
V12_AIR_BORE_D = 136;
V12_SEAL_RECESS_D = 1.2;
V12_DECK_SEAM_GAP = 0.3; // total split gap; tabs detour around their cardinal axes

V12_M3_AXIS = 74;
V12_M3_D = 3.4;
V12_M3_CB_D = 8.2;
V12_M3_CB_DEPTH = 3.5;
V12_M3_WASHER_T = 0.5;

V12_M4_D = 4.6;
V12_M4_HEAD_D = 8.4;
V12_M4_CS_DEPTH = 2.2;
V12_M4_NUT_AF = 7.3;
V12_M4_NUT_H = 3.4;
// Starting fit allowance for the modeled-baseline M4 hex nut. This is an across-flats
// allowance, not a claim about any particular printer or hardware batch.
// Measure the purchased nuts and dry-fit a printed pocket before assembly.
V12_M4_NUT_CLEARANCE = 0.25;
// A small vertical allowance keeps the pocket roof from becoming the first
// interference when layer height, first-layer spread, or nut thickness varies.
V12_M4_NUT_Z_CLEARANCE = 0.20;

// `use` imports functions and modules, but not ordinary variables. Keep these
// accessors public so interface tests can exercise command-line overrides of
// the pocket contract without duplicating its modeled-baseline dimensions.
function v12_m4_nut_af() = V12_M4_NUT_AF;
function v12_m4_nut_h() = V12_M4_NUT_H;
function v12_m4_nut_clearance() = V12_M4_NUT_CLEARANCE;
function v12_m4_nut_z_clearance() = V12_M4_NUT_Z_CLEARANCE;

V12_TAB_R = 6.5;
V12_TAB_CLEAR_R = 6.8;

V12_BRIDGE_W = 44;
V12_BRIDGE_D = 24;
V12_BRIDGE_R = 3;
V12_BRIDGE_CENTERS = [
    [0, V12_D_TBD / 2 - 22.5],
    [0, -(V12_D_TBD / 2 - 22.5)],
    [V12_W_TBD / 2 - 26.5, 0],
    [-(V12_W_TBD / 2 - 26.5), 0]
];

// Original V2 upper stack placement. These values are intentionally explicit
// so this validation model does not depend on private imported globals.
V2_BASE_Z = 2 * V12_DECK_T;
V2_SHELL_Z = V2_BASE_Z + 5;
V2_LID_Z = V2_SHELL_Z + 40;
V2_CRADLE_Z = V2_LID_Z + 5;
V2_INSERT_T = 3;
V2_GASKET_FREE_H = 4;
V2_GASKET_COMPRESSED_H = 3;

V12_PARTS = [
    "gauge_ne", "gauge_nw", "gauge_sw", "gauge_se",
    "deck_ne", "deck_nw", "deck_sw", "deck_se", "deck",
    "collar", "bridge", "assembly", "gauge_assembly",
    "coupon_ne", "coupon_se", "coupon_collar"
];
V12_AXES = [
    [V12_M3_AXIS, 0], [0, V12_M3_AXIS],
    [-V12_M3_AXIS, 0], [0, -V12_M3_AXIS]
];
V12_COLLAR_M4 = [
    [82, 46], [82, -46], [-82, 46], [-82, -46],
    [44, 76], [44, -76], [-44, 76], [-44, -76]
];
V12_BRIDGE_HOLES = [
    [12, V12_BRIDGE_CENTERS[0][1]], [-12, V12_BRIDGE_CENTERS[0][1]],
    [12, V12_BRIDGE_CENTERS[1][1]], [-12, V12_BRIDGE_CENTERS[1][1]],
    [V12_BRIDGE_CENTERS[2][0], 12], [V12_BRIDGE_CENTERS[2][0], -12],
    [V12_BRIDGE_CENTERS[3][0], 12], [V12_BRIDGE_CENTERS[3][0], -12]
];

EPS = 0.02;

function v12_is_gauge_part(part) =
    part == "gauge_ne" || part == "gauge_nw" ||
    part == "gauge_sw" || part == "gauge_se" ||
    part == "gauge_assembly";

function v12_owner_axis(sx, sy) =
    sx > 0 && sy > 0 ? [V12_M3_AXIS, 0] :
    sx < 0 && sy > 0 ? [0, V12_M3_AXIS] :
    sx < 0 && sy < 0 ? [-V12_M3_AXIS, 0] :
    [0, -V12_M3_AXIS];

function v12_same_point(a, b) = a[0] == b[0] && a[1] == b[1];

assert(len([for (part = V12_PARTS) if (part == PART) part]) == 1,
       "Unknown PART selector");
assert(V12_W_TBD > V12_GAUGE_OPEN_W_TBD + 2 * V12_GAUGE_SEAM_GAP,
       "V12 outer width must exceed gauge opening");
assert(V12_D_TBD > V12_GAUGE_OPEN_D_TBD +
       2 * abs(V12_GAUGE_OPEN_Y_TBD) + 2 * V12_GAUGE_SEAM_GAP,
       "V12 outer depth must contain the offset gauge opening");
assert(V12_R_TBD > 0 && V12_R_TBD < min(V12_W_TBD, V12_D_TBD) / 2,
       "Invalid V12 outer corner radius");
assert(V12_GAUGE_T > 0 && V12_GAUGE_SEAM_GAP >= 0,
       "Invalid gauge thickness or seam gap");
assert(V12_GAUGE_OPEN_W_TBD > 0 && V12_GAUGE_OPEN_D_TBD > 0,
       "Invalid gauge opening");

// Gauge selectors remain useful for a later panel measurement even if a
// proposed structural footprint is temporarily too small for the collar.
if (!v12_is_gauge_part(PART)) {
    assert(V12_W_TBD >= V12_COLLAR_W && V12_D_TBD >= V12_COLLAR_D,
           "V12 footprint must contain the collar");
    assert(V12_COLLAR_W <= V12_W_TBD && V12_COLLAR_D <= V12_D_TBD,
           "Collar exceeds V12 footprint");
    assert(V12_AIR_BORE_D == 136,
           "V12 air bore must remain the fixed 136 mm mating contract");
    assert(V12_AIR_BORE_D < min(V12_COLLAR_W, V12_COLLAR_D),
           "Air bore must fit inside collar");
    assert(V12_COLLAR_T == V12_DECK_T,
           "Collar and deck thicknesses must match the two-layer stack");
    assert(2 * V12_SEAL_RECESS_D < V12_COLLAR_T,
           "Upper and lower collar seal recesses consume the collar");
    assert(V12_SEAL_RECESS_D > 0 && V12_SEAL_RECESS_D < V12_COLLAR_T / 2,
           "Invalid collar seal recess depth");
    assert(V12_M3_AXIS - V12_M3_CB_D / 2 - V12_AIR_BORE_D / 2 > 1.8,
           "M3 counterbore must clear the 136 mm bore by more than 1.8 mm");
    assert(V12_M3_CB_DEPTH > V12_M3_WASHER_T &&
           V12_M3_CB_DEPTH < V12_DECK_T,
           "M3 counterbore / washer stack is invalid");
    assert(V12_DECK_T > V12_M4_NUT_H,
           "Deck must be thick enough for underside M4 nuts");
    assert(V12_M4_CS_DEPTH > 0 && V12_M4_CS_DEPTH < V12_DECK_T,
           "Invalid M4 countersink depth");
    assert(V12_M4_NUT_CLEARANCE >= 0 && V12_M4_NUT_Z_CLEARANCE >= 0,
           "M4 nut clearances must be nonnegative");
    assert(V12_M4_NUT_AF > 0 && V12_M4_NUT_H > 0 &&
           V12_M4_NUT_H + V12_M4_NUT_Z_CLEARANCE < V12_DECK_T,
           "M4 nut pocket must leave a deck roof");
    assert(V12_TAB_CLEAR_R > V12_TAB_R && V12_TAB_R > V12_M3_CB_D / 2,
           "Tab and clearance radii are invalid");
    assert(V12_TAB_R + V12_M3_AXIS < V12_W_TBD / 2 &&
           V12_TAB_R + V12_M3_AXIS < V12_D_TBD / 2,
           "M3 tab must remain inside the V12 footprint");
    assert(V12_W_TBD / 2 + V12_TAB_R < 200 &&
           V12_D_TBD / 2 + V12_TAB_R < 200,
           "Structural tile maximum dimension including tabs must remain below 200 mm");
    assert(V12_BRIDGE_W > V12_M4_HEAD_D &&
           V12_BRIDGE_D > V12_M4_HEAD_D,
           "Bridge must contain its countersunk M4 heads");
    assert(V12_BRIDGE_D / 2 < V12_D_TBD / 2 &&
           V12_BRIDGE_W / 2 < V12_W_TBD / 2,
           "Bridge footprint exceeds V12 envelope");
    assert(V12_D_TBD / 2 - 22.5 > V12_BRIDGE_D / 2 &&
           V12_W_TBD / 2 - 26.5 > V12_BRIDGE_D / 2,
           "Bridge centers do not clear the V12 edge");
    assert(V12_D_TBD / 2 - 22.5 - V12_BRIDGE_D / 2 > V12_COLLAR_D / 2 &&
           V12_W_TBD / 2 - 26.5 - V12_BRIDGE_D / 2 > V12_COLLAR_W / 2,
           "Bridge pieces must clear the collar footprint");
}

module v12_rr(w, d, r) {
    offset(r = r) square([w - 2 * r, d - 2 * r], center = true);
}

module v12_slab(w, d, h, r) {
    linear_extrude(height = h) v12_rr(w, d, r);
}

module v12_bore(h, d) {
    translate([0, 0, -EPS]) cylinder(d = d, h = h + 2 * EPS);
}

module v12_hex_nut(af, h) {
    cylinder(d = af / cos(30), h = h, $fn = 6);
}

module v12_top_countersink(h, bore_d, head_d, depth) {
    translate([0, 0, h - depth])
        cylinder(d1 = bore_d, d2 = head_d, h = depth + EPS);
}

module v12_annulus(outer_d, inner_d, h) {
    difference() {
        cylinder(d = outer_d, h = h);
        translate([0, 0, -EPS]) cylinder(d = inner_d, h = h + 2 * EPS);
    }
}

module v12_quadrant_clip(sx, sy, seam_gap) {
    clip_w = V12_W_TBD / 2 - seam_gap / 2;
    clip_d = V12_D_TBD / 2 - seam_gap / 2;
    clip_x = sx * (V12_W_TBD / 4 + seam_gap / 4);
    clip_y = sy * (V12_D_TBD / 4 + seam_gap / 4);
    translate([clip_x, clip_y, V12_DECK_T / 2])
        cube([clip_w, clip_d, V12_DECK_T + 2 * EPS], center = true);
}
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

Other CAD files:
cad/upright_v2/v12_validation/stl/deck_se.stl
cad/upright_v2/v12_validation/stl/deck_sw.stl
cad/upright_v2/v12_validation/stl/gauge_se.stl
cad/upright_v2/v12_validation/stl/coupon_collar.stl
cad/upright_v1/upright_macbook_140mm_pressure_dock_v1.scad
archive/early_cadquery/upright_macbook_140mm_pressure_dock_v1.step
cad/upright_v1/upright_macbook_140mm_pressure_dock_v1.stl
cad/upright_v2/stl/foot.stl
cad/upright_v2/v12_validation/stl/bridge.stl
cad/upright_v2/v12_validation/stl/collar.stl
cad/upright_v2/v12_validation/stl/coupon_se.stl
cad/upright_v2/v12_validation/stl/gauge_ne.stl
cad/upright_v2/v12_validation/stl/gauge_nw.stl

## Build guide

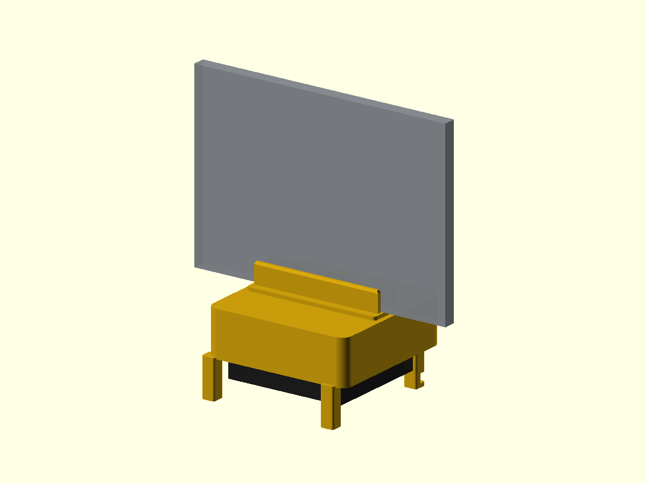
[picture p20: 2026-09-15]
renders/upright_macbook_140mm_pressure_dock_v1_assembly_preview.png

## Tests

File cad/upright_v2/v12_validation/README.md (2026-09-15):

# V2 on the llano V12

This adapter replaces V2's fan cartridge and feet with a wide, sealed deck for
the llano V12. The existing V2 base, shell, lid, cradle, and laptop insert stay
unchanged. Air enters through the same 136 mm bottom opening.

The V12 pushes room air through the deck and plenum into the Mac's center hinge
intake. The two outer hinge exhausts and side chassis intakes stay open. Do not
reverse this center-fed path to extract air. See the
[airflow evidence and direction check](../../../docs/VENT_GEOMETRY.md#airflow-direction).

**Print the footprint gauge first.** The user has not fit-checked the existing
V12 panels. The 381 × 269 mm outline is taken from those STL files, not measured
from the cooler. This adapter is for construction and unpowered fit checks until
the support, seal, restraint, and load checks below pass. Do not put the Mac on
the gauge or power the V12 beneath an unsecured deck.

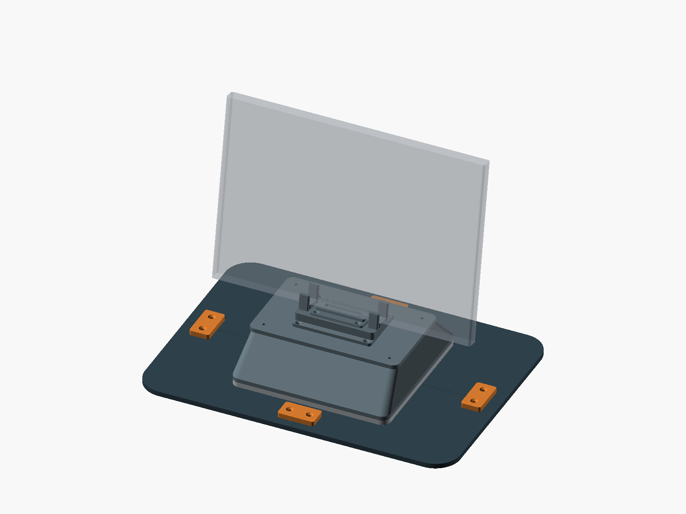
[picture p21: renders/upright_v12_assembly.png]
V2 upper assembly on the four-tile V12 validation deck


The translucent laptop is an envelope reference. The cooler, foam, and housing
restraint are not modeled. [Exploded adapter view](../../../renders/upright_v12_exploded.png).

## First prints

Use the [STL snapshot](stl/) or build from the project root:

```bash
make gauge-v12
make coupon-v12
```

Both commands write to `build/v12_validation/`. Set `OPENSCAD` if needed.

1. Print one each of `gauge_ne`, `gauge_nw`, `gauge_sw`, and `gauge_se`. These
   1.2 mm-thick pieces follow the old panels' outer profile and inner opening.
   In the source, +X is east and +Y is north; these are assembly labels, not a
   verified orientation on the V12. Before removing each tile from the print
   bed, mark its quadrant and a +Y arrow on top with a pen. The gauge has no
   printed IDs or alignment keys; do not add labels beneath its contact surface.
2. Assemble the gauge on a flat table, with a 0.3 mm gap between straight seams.
   Light tape is sufficient for this unloaded gauge. Verify the assembled outer
   width and depth with a ruler before judging fit on the cooler.
3. Place it on the unpowered V12. Check the full outer outline, foam inner/outer
   edges, raised features, controls, and cable exits. Photograph the fit from
   above and from the side. The gauge checks coverage, not airtightness.
4. Measure the foam height and compression, the deck angle, and where a rigid
   plate can bear load. Identify a positive restraint to the cooler housing that
   leaves its intake, controls, and cables clear. Foam friction is not a restraint.
5. Print `coupon_ne`, `coupon_se`, and `coupon_collar`. They reproduce the actual
   +X seam tab and M3 recess. Fit the two deck pieces beneath the collar coupon,
   using the intended M3 screw, washer, and a loose nut above. Confirm clearance,
   full head recess, and no cracking or separation when lightly tightened.

The default gauge window is 291 × 170 mm, centered at Y = 14.5 mm, and the outer
corner radius is 30 mm. These values reproduce the legacy panel geometry. They
are not a specification for the V12's foam or air outlet. Adjust the `_TBD`
parameters in the source and repeat the fit check if the outline misses.

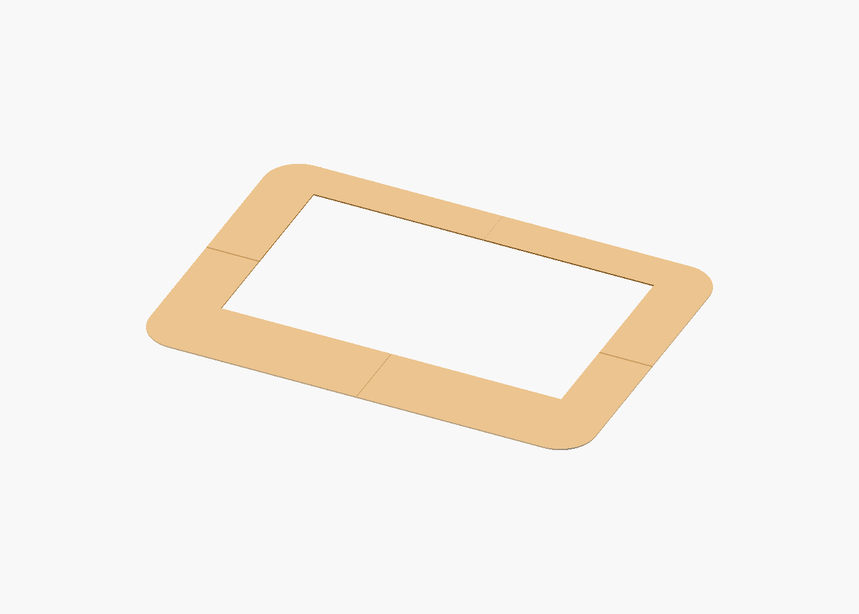
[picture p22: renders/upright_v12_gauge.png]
Four thin gauge tiles with the legacy offset rectangular opening


## Adapter construction

After the gauge and joint coupon pass, export and check the complete adapter:

```bash
make stl-v12
make check-v12 PYTHON=.venv/bin/python
make preview-v12
```

Install the Python dependencies as described in the [V2 guide](../README.md).
`check-v12` checks every mesh, mating surfaces, screw envelopes, and the full
lower air path. It does not establish printed strength or actual cooler fit.

The deck uses four 6 mm tiles. A continuous 190 × 180 × 6 mm collar joins them
under V2, and four outer bridges hold the seam ends. Eight off-seam collar screws
and the bridge screws provide the structural joints. The round seam tabs locate
the tiles and keep each M3 head/washer inside one piece. Tape only seals air.

Print one of each `deck_*` part, one `collar`, and four `bridge` parts. The gauge
and coupon parts are not installed in the finished adapter. The deck is filled
except for its 136 mm inlet and fasteners; do not use the gauge's large rectangular
opening as a structural deck.

### Verified print envelopes

These are measured STL bounding boxes, not physical fit measurements. All 13
individual exports are watertight single solids. Each part fits within 200 mm
in X and Y before adding a brim; allow extra bed space for your slicer settings.

| Part | X × Y × Z, mm | Quantity |
|---|---|---:|
| `gauge_ne`, `gauge_nw`, `gauge_sw`, `gauge_se` | 190.35 × 134.35 × 1.20 | 1 each, gauge only |
| `coupon_ne` | 22.74 × 21.50 × 6.00 | 1, joint test only |
| `coupon_se` | 22.74 × 14.85 × 6.00 | 1, joint test only |
| `coupon_collar` | 22.74 × 30.00 × 6.00 | 1, joint test only |
| `deck_ne`, `deck_sw` | 190.35 × 141.00 × 6.00 | 1 each |
| `deck_nw`, `deck_se` | 197.00 × 134.35 × 6.00 | 1 each |
| `collar` | 190.00 × 180.00 × 6.00 | 1 |
| `bridge` | 44.00 × 24.00 × 6.00 | 4 |

The assembled printed envelope, including the existing V2 upper parts but not
the Mac or cooler, is 381 × 269 × 91.24 mm. Print the deck tiles flat with their
nut pockets and M3 counterbores facing the bed. Print the collar and bridges flat
with their countersinks facing up. Inspect the pocket roofs for bridge sag and
clear them before fitting hardware. Check the collar's face-down, 3 mm-wide seal
recess in the slicer too. First-layer spread must not narrow that recess or stop
the tiles from fitting. Use the same orientation for the coupons.

## Default hardware

These starting lengths apply to the 6 mm deck and 6 mm collar. Check purchased
hardware and actual printed dimensions before tightening.

| Joint | Hardware | Access |
|---|---|---|
| Collar to deck | 8 × M4 × 12 countersunk, 8 M4 nuts | From above, before V2 covers the collar |
| Four outer bridges | 8 × M4 × 12 countersunk, 8 M4 nuts | From above |
| V2 base to adapter | 4 × M3 × 16 pan head, 4 washers, V2's 4 cartridge nuts | From below, with adapter off the V12 |

The M4 × 12 length has almost no spare length across the two 6 mm layers.
Dry-fit a complete screw/nut joint before assembly and check thread engagement
without underside protrusion. The deck pockets start with a 0.25 mm
across-flats allowance and a 0.20 mm vertical allowance around the modeled
7.3 mm AF × 3.4 mm nut baseline. These are exposed starting parameters, not universal
FDM tolerances. The automated `m4_nut_fit` case checks the modeled-baseline nut plus a
separate 0.20 mm AF / 0.15 mm height test envelope in all 16 pockets, including
the pocket walls and roof; regression cases deliberately remove each source
allowance and must report a collision. Measure the purchased nuts and dry-fit
every pocket anyway, since first-layer spread, elephant foot, layer anisotropy,
printer calibration, and hardware variation are not certified by CAD.

Use washers no larger than 7 mm outside diameter. The M3 head recess is 8.2 mm
diameter and 3.5 mm deep. A 2.5 mm-high pan head plus a 0.5 mm washer sits about
0.5 mm above the deck underside. The 16 mm screw then extends about 2 mm beyond
V2's base into the empty plenum. Check this stack with your actual hardware.
Do not leave metal projecting below the deck.

Only 1.9 mm of printed material separates an M3 head recess from the inlet.
Inspect this ligament and the 2.5 mm recess floor closely. Use low tightening
force; reject cracks, voids, crushed layers, or a washer that cuts into the seat.
Increasing recess diameter needs another clearance and strength check.

## Assembly and seals

1. Deburr the tiles and dry-fit their tabs. Check the full outline, diagonals,
   flatness, and the 136 mm inlet.
2. Install the 16 captive M4 nuts from the deck underside. Fit the collar's lower
   annular seal before bolting the collar and four bridges onto the deck. All
   upper countersunk heads must be flush.
3. Fit the collar's upper annular seal. Both recesses cover diameters 136 to
   142 mm and are 1.2 mm deep. Choose foam that compresses into the recess so the
   rigid faces seat. The lower seal crosses tile seams; inspect those joints.
4. Remove V2's fan, cartridge, and all four feet. Retain the four cartridge nuts
   in its base. Seal the unused foot screw holes on the pressure side. Install
   or check the shell's underside nuts before the collar covers them.
5. Place the V2 base on the collar and insert the four M3 screws from below the
   deck. Check nut engagement and head recess. The rest of V2 assembles as in its
   [guide](../README.md), with the blank laptop insert first.
6. Seal every underside seam and fastener penetration with thin removable film,
   tape, or suitable sealant. Follow the curved seam around each tab. Keep the
   sealing surface flat; no stacked tape ridges beneath the cooler's foam land.
   Seal around the M3 heads as well as the M4 nut pockets.

All underside hardware needs access off the cooler. Do not add a second fan in
series, leave V2's fan in place, or use its feet as supports on the V12.

## Before a powered test

The deck is not secured to the V12 by its foam seal. Pressure can lift the deck,
and the upright laptop adds an overturning load. **Positive housing restraint is
required.** No strap route or attachment point is modeled because the actual
cooler has not been measured. Do not drill the V12 or route straps across its
inlet or controls to make this prototype fit.

Load-test the complete adapter with a padded dummy on a rigid test fixture before
using the Mac. Then verify its support and restraint on the unpowered V12. Check
for deck bow, seam opening, collar lift, slipping, and tipping under cable load.
The V2 cradle's 10° lean is relative to the deck, not the desk; check the actual
combined angle and keep the laptop stable. Do not assume the V12's tilted stand
settings are suitable for an upright laptop.

After the fit, restraint, and load checks pass, leak-test the blank-insert assembly
without the Mac. Confirm the separate [Mac-side fit requirements](../README.md)
before using the experimental open insert. Start the V12 at low speed and stop
if the deck moves, seals lift, or exhaust is obstructed.

This arrangement tests V2's airflow path with the V12 pressure source. It does
not establish that a standalone 140 mm fan will produce the same result. Use the
[benchmark plan](../../../docs/BENCHMARK_PLAN.md) to compare sustained work.

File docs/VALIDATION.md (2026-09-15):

# V2 and V12 adapter validation record

Checked September 15, 2026 with OpenSCAD 2026.01.02 (Manifold, macOS x86_64),
Python 3.12, and trimesh 5.1.0. These are digital geometry checks, not physical
test results.

The Python checks were repeated in a clean virtual environment with only
`tools/requirements.txt` installed. All five validator regression tests and
the nine rebuilt and published V2 meshes pass. NetworkX is declared explicitly
because trimesh's connected-solid checks need a graph backend.

## Export checks

`make stl-v2` and `make check-v2` pass for all nine default parts. Each export is
a single connected solid with finite coordinates, consistent winding, positive
volume, and a watertight surface. The [assembly guide](../cad/upright_v2/README.md)
lists each measured envelope and print quantity. The assembled printed envelope
is 190 × 180 × 129.24 mm at 10° lean.

The cradle was also exported at 8° and 12° lean and passed the same checks:

| Lean | Cradle envelope, mm |
|---|---|
| 8° | 96 × 64 × 29.46 |
| 10° | 96 × 64 × 29.24 |
| 12° | 96 × 64 × 29.62 |

Boolean intersection checks found no volumetric interference in the default
assembly between the cradle/insert, cradle/laptop envelope, base/cartridge,
shell/lid, cartridge/feet, cradle/lid, shell/base, compressed gasket/laptop
envelope, or keyed feet/base. A 1 mm centerline probe passes through the open
insert and rigid air path. The four lower shell fixings clear a 7 mm diameter,
3 mm tall screw-head envelope. Cradle/insert, cradle/laptop, and centerline checks
also pass at 8° and 12°. Coplanar contact produced numerical fragments below
0.000001 mm³ in two checks; those are not physical interference.

Assembly and exploded PNGs were rendered from the final CAD and visually checked.
The laptop is only an external-envelope proxy, with no modeled vent openings.

## V12 adapter checks

`make stl-v12` and `make check-v12` pass for all 13 default adapter parts: four
gauges, three joint coupons, four deck tiles, a collar, and a bridge. Each is a
watertight single solid with consistent winding, positive volume, and finite
coordinates. The [adapter guide](../cad/upright_v2/v12_validation/README.md) lists
measured print envelopes and quantities. The assembled printed envelope is
381 × 269 × 91.24 mm, excluding the laptop and V12 cooler.

The 16 cases in `tools/check_v12.py` include an 8 mm³ positive control, an empty
negative control, and intentionally overlapping real deck/collar and oversized
nut-pocket controls. The remaining cases check tile overlap, deck/collar and
base/collar contact, bridge clearance, separate M3 and M4 screw envelopes, the
full lower inlet, an unobstructed gauge window, actual deck material thickness
away from the tabs, and nut fit in all 16 M4 pockets. The nut-fit case models a
modeled-baseline hex nut plus a documented AF/height test allowance and intersects that
solid with the actual deck, so both pocket walls and the roof are checked. Two
additional runs set the source lateral or vertical allowance to zero and must
fail with a collision, proving the check is sensitive to undersized or
too-shallow pockets. This models a conservative starting envelope, not all FDM
layer, first-layer, printer, or hardware variation; purchased nuts still need
a physical dry-fit. The nearly flush M4 × 12 stack also requires a printed
hardware check.

The first Linux run rebuilt all 13 parts successfully, but CGAL exported the
intentional contact planes in three interface tests as zero-thickness surfaces.
Those probes now exclude 0.001 mm at the intended contact plane; print geometry
is unchanged. Moving the collar probe down 0.1 mm creates 0.099 mm of real
deck/collar overlap, which must still produce positive volume. Warning failures
remain enabled, so unrelated export problems cannot pass as empty intersections.
These probes check interference beyond that stated
allowance, not mathematical separation at an exact shared face.

Assembly, exploded, and gauge previews were rendered from the final source and
visually checked. The gauge preview contains only its four unloaded pieces; it
does not imply that the gauge supports the laptop. Original V2 CAD and STL
snapshots are unchanged. Desk clearance and lid-rib changes are deferred.

The adapter is still an unpowered fit/construction prototype. The legacy cooler
outline has not been fit-checked; deck support, seal compression, housing
restraint, printed joint strength, and stability remain physical prerequisites.
The 1.9 mm M3 recess-to-inlet ligament needs a coupon test before a full print.
Digital noninterference does not establish these properties.

## V1 preservation

`make stl` still rebuilds V1 as a watertight solid measuring
176 × 176 × 129.5 mm. Its source and checked-in STL are unchanged:

```text
e432872113be753e4f137b082bf2ea03bc9675405cee6762a64ffd6b11a1ef1b  V1 SCAD
7eab28b8b06bcefbfc5c955d842ac215d595b83e85731d4f61e71c814b38869b  V1 STL
```

## What remains untested

- Actual M5 Max vent boundaries, closed-hinge recess, and padded contact points.
- Printed tolerances, layer strength, lid deflection, stability, and cable loads.
- Gasket compression, seam and fastener leaks, exhaust recirculation.
- Fan pressure/flow, acoustics, and sustained workload performance.

Use the blank insert for the first fit and leakage checks. Install all soft pads,
load-test with a dummy, and fit a fan guard before powered bench testing. A
watertight mesh does not prove that an FDM print or its joints are airtight.
Follow the [assembly guide](../cad/upright_v2/README.md) and
[benchmark plan](BENCHMARK_PLAN.md).

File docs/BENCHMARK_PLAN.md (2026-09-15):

# Benchmark Plan

The purpose of benchmarking is to determine whether external cooling raises **sustained useful performance** on the user's actual 14-inch M5 Max and to infer how much fan pressure the upright dock really needs.

## Test order

1. Stock clamshell, no external cooling
2. V12 present but with the custom seal/adapter removed or deliberately unsealed
3. V12 + sealed adapter
4. V12 + sealed adapter at multiple fan speeds
5. Upright V2 on the V12 using the [validation deck](../cad/upright_v2/v12_validation/README.md), after its fit, restraint, load, and leak checks pass
6. The same Upright V2 upper assembly with a quiet 140 mm fan
7. Upright V2 with a higher-static-pressure 140 mm fan, if needed

The V12 deck removes V2's standalone fan and feet. Keep the V2 laptop insert,
gasket, machine settings, and workload fixed when changing pressure sources.
V12-powered success validates that combination, not the standalone fan's pressure
capability. A fan-off run on an obstructed adapter is not the stock baseline.

Do not consider an internal thermal-pad modification until these results are understood.

## Workloads

Use workloads that resemble actual use rather than only short synthetic tests.

### AI

Use the same model, quantization, context, prompt, and generation settings for every run. Record at minimum:

- prompt processing / prefill speed where available
- decode tokens/sec
- time to first token
- total wall time
- sustained GPU/SoC power if available
- GPU/CPU clocks if available
- fan RPM and temperatures

A 20-30 minute repeated workload is preferable to a single short prompt.

### Compiles

Use a reproducible clean build large enough to heat-soak the machine. Record:

- wall-clock compile time
- sustained CPU package power
- P-core clocks if available
- Apple fan RPM
- temperatures

Repeat each configuration enough times to distinguish thermal behavior from build-cache/noise effects.

## Fan-speed sweep

The V12 is useful as an experimental pressure source. The most valuable first sweep is approximately:

- low
- medium-low
- medium
- medium-high
- maximum

Use the V12's actual available RPM/readout points if exposed rather than forcing arbitrary targets.

The design decision to make afterward is not "which RPM is coolest?" but rather:

> At what fan setting does sustained package power / workload throughput stop meaningfully improving?

If performance plateaus at low or moderate V12 speed, the final upright dock can likely use a quieter conventional 140 mm fan. If performance continues scaling near maximum V12 speed, use a high-static-pressure fan or blower instead.

## Keep ambient conditions sane

- Record room temperature.
- Let the machine return to a similar starting state between cold-start comparisons, or deliberately compare steady-state repeated loads.
- Keep power mode and charger constant.
- Keep display/clamshell state constant.
- Avoid changing unrelated software between A/B runs.

## Success criteria

Primary: more completed work per unit time after thermal equilibrium.

Secondary:

- higher sustained SoC / CPU / GPU power at similar temperature
- higher sustained clocks
- lower Apple internal-fan RPM at equal performance

Temperature by itself is not the main success metric.

## Standalone V2 follow-up experiments

External review on September 15, 2026 raised these items. They are test proposals,
not changes to the original V2 geometry in the V12-adapter work. The user chose
to finish the V12 adapter first and defer standalone revisions:

- Compare the 20 mm desk intake gap with 30-35 mm before selecting the standalone
  fan. A nominal 140 mm circle has 154 cm² area; a 20 mm peripheral approach gives
  about 88-112 cm² depending on a circular or square boundary. At 35 mm that range
  is about 154-196 cm². These are area estimates, not pressure-loss or fan-curve
  measurements. Test 38 mm-thick fans separately and record their actual clearance.
- After measuring the Mac, compare safe insert sizes while keeping the rest of
  the airflow path fixed. Candidates are 44 × 8, 48 × 8, and 48 × 10 mm, plus the
  maximum opening justified by actual intake/exhaust boundaries. Rounded corners
  slightly reduce the quoted rectangular areas. Use the blank for fit/leak checks,
  not as a powered laptop-cooling configuration.
- Recheck the 96 mm-wide raised cradle and stop locations against the actual Max.
  Narrowing supports may increase exhaust clearance; moving them inward can also
  approach the center intake and change where the load lands. Measure first.
- Consider shallow underside lid ribs if the dummy-load/cable-load test shows
  flex. Any ribs must preserve the air path, nut access, shell-boss clearance,
  and a workable print orientation. Do not treat static laptop weight as the only
  load case.

V12-powered testing isolates the upper airflow path without the standalone fan's
desk-intake restriction. Leave cosmetic redesign until the pressure, interface,
and structural tests establish which geometry is worth keeping.

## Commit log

2026-09-15 chore: preserve original pressure-dock prototypes
    Import the supplied V1, split V12 adapter, benchmark plan, and archived CadQuery design without changing their geometry. Verified V1 and both adapter STLs as watertight single solids.
    [panel_left.stl, panel_right.stl, upright_macbook_140mm_pressure_dock_v1.scad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]
2026-09-15 feat: add modular upright v2 fit-check prototype
    The supplied base-M5 visualization places outer hinge banks inside the V1 outlet span; it does not establish a final Max interface. Keep the experimental center opening replaceable and default to a blank insert.
    Add the tapered shell, serviceable 140 mm fan cartridge, tilted padded cradle, keyed feet, verified STL snapshot, and mesh validation workflow. All nine default meshes and both lean endpoints pass local checks.
    [base.stl, cartridge.stl, cradle.stl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]
2026-09-15 docs: document v2 assembly and unverified laptop interface
    Separate mesh measurements from physical fit and performance claims. Include model provenance, hardware and sealing instructions, load and fan-guard requirements, and rendered assembly views.
2026-09-15 fix: declare graph backend for clean mesh-validation installs
    The local CAD environment supplied SciPy implicitly, so the first clean CI install had no graph engine for connected-solid checks. Declare NetworkX and verify all five regression tests plus the V1 and V2 meshes in a fresh virtual environment.
    Record direct-main publication and the physical validation follow-ups.
2026-09-15 feat: add provisional llano v12 validation deck for upright v2
    The legacy V12 outline has not been fit-checked. Add a thin four-piece gauge and joint coupons before the full bolted deck, while preserving the existing V2 upper assembly.
    Publish 13 checked STL variants, adapter previews, and 11 interface regression cases. Document pressure into the center hinge intake, required cooler restraint and hardware checks, and deferred stand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
    Claude-Session: Codex thread 01a0a637-ac09-7372-bea0-55788c053bd6
    [bridge.stl, collar.stl, coupon_collar.stl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]
2026-09-15 fix: make v12 contact probes portable across geometry engines
    CGAL exports intentional shared faces as zero-thickness surfaces, unlike Manifold. Separate only the test probes by 0.001 mm and require an injected real deck/collar collision to remain detectable. Keep export warnings and volume thresholds strict; printable CAD and STLs are unchanged.
    Verify all 12 Manifold cases, the affected CGAL cases, and the zero-allowance warning regression. Split CI mesh and interface steps for clearer progress.
    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
    [v12_interfaces.scad]
2026-09-15 fix: validate v12 m4 nut pocket fit
    The old V12 M4 check modeled only the screw envelope, leaving nut pocket walls, roof clearance, and print-fit allowances untested. Add parameterized across-flats and vertical starting allowances, test a nut envelope in all 16 pockets, and add zero-clearance collision regressions.
    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
    [deck_ne.stl, deck_nw.stl, deck_se.stl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]
